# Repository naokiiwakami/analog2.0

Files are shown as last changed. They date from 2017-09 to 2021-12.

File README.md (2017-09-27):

# Analog2.0

Analog2.0 は、はじめての人でも作りやすいように設計されたモジュラーシステムシンセサイザーです。

このリポジトリには、Analog2.0 の製作を支援するための以下のようなリソースが置いてあります

- 回路図のイメージファイル
- 基板のレイアウトのファイル
- パネルなどのアートワークファイル
- ファームウェアとソースコード

また、製作ガイドをこのリポジトリの Wiki ページに掲載しています。

https://github.com/naokiiwakami/analog2.0/wiki

Analog2.0 は、以下の主要モジュールで構成されています。このリポジトリには、モジュールごとのディレクトリがあり、各ディレクトリの下にそのモジュール製作のためのリソースが置いてあります。

- `02_panel` パネル
- `03_power` 電源モジュール
- `04_noise_mixer` ノイズ・ジェネレータとミキサ
- `05_vca` VCA -- 電圧制御増幅器
- `06_vco` VCO -- 電圧制御発振器
- `07_eg` エンベロープ・ジェネレータ
- `08_lfo` LFO -- 低周波発振器
- `09_vcf` VCF -- 電圧制御フィルタ
- `10_miniboard` MIDI / CV 変換器

参考として、Analog2.0 のシステムに準じてはいないけれどもシンセサイザーのモジュールとして使えるものが `others` ディレクトリにおいてあります。

- リングモジュレータ
- グラフィックイコライザ
- レゾネータ
- フェーズシフタ
- ゲートディレイ
- アナログシーケンサ

各モジュールのドキュメントは現在メインテナンスしていません。最新のドキュメントは、書籍「達人と作るアナログシンセサイザー自作入門　改訂版2017」として出版されています

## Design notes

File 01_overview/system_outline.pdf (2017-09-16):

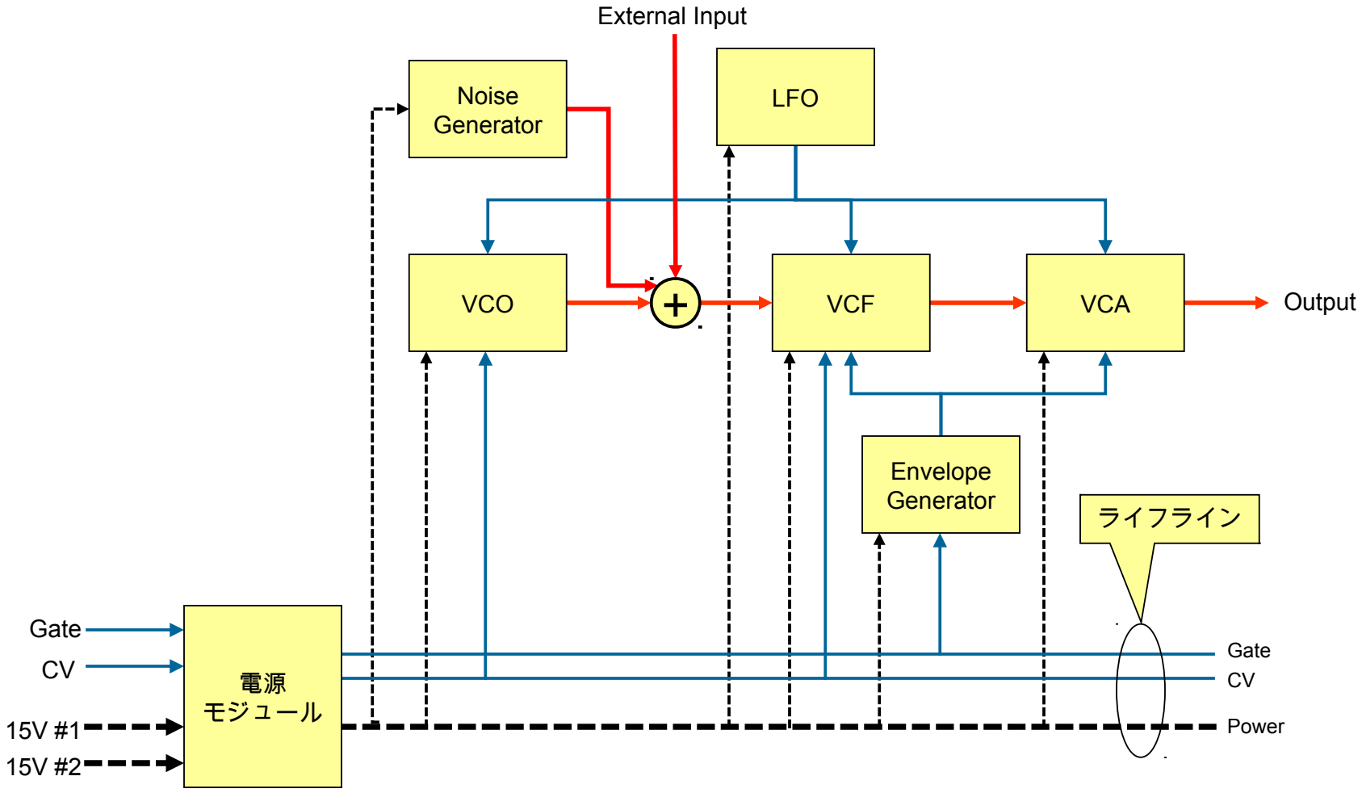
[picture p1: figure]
External Input; Output; Gate; ライフライン; Gate CV; Power; VCO; Noise Generator; VCF; VCA; LFO; Envelope Generator; 電源 モジュール

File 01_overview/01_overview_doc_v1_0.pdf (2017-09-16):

### Analog 2.0 ドキュメンテーション

### Vol. 1

## Analog2.0 の概要

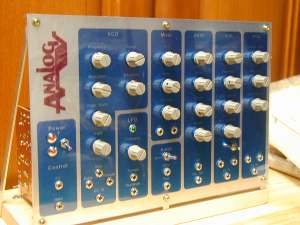
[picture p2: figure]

バージョン：1.0
作成日：2008 年 1 月 24 日

Analog2.0 ドキュメンテーション
Vol.1 Analog2.0 の概要
Copyright (C) Naoki Iwakami. All rights reserved. | 2

目次

1. このドキュメントについて | 3 ...... 3

Copyright (C) Naoki Iwakami. All rights reserved. | 3
1. このドキュメントについて

このドキュメントは、アナログシンセサイザーシステム Analog2.0 の概要を解説します。

このドキュメントは以下のように構成されています。

- Analog2.0 とは
- Analog2.0 の構成
- ドキュメントのリリース予定
2. Analog2.0 とは

Analog2.0 は、アナログシンセサイザーシステムの設計の名称です。以下のようなコンセ プトのもとに設計されており、製作を解説するドキュメントの形式で公開されます。

【対象】 | アナログシンセサイザーを作ってみたい人。ただ作るだけでなく、いずれ は自分のカラーを出して作りたい人。
【構成】 | 最小構成のモノフォニック。内部結線を行い、パッチングをしなくても音 は出せるがパッチも可能にする。機能モジュールごとに基板を分け、拡張 や改造を容易にする。

【必要な知識】 オームの法則がわかる。電流と電圧の違いがわかる。アナログオーディオ
| 信号とは音波を電圧に置き換えたものだということを理解している。

【必要な道具】 ハンダゴテ（と半田）、ラジオペンチ、ニッパー、ドライバー、ドリル、
| テスター、アンプとスピーカー、PC。
【進め方】 | まずパネルを製作する。定期的にシンセモジュールの製作方法を１個ずつ リリース。これを組み立ててパネルにはめてゆく。製作方法の説明に加え て毎回テーマを決めてアナログシンセサイザーの動作原理を解説する。
【部品】 | 全ての回路を現状入手可能な部品のみで構成する。
【提供物】 | 製作ガイドを提供。部品および基板の提供はこのプロジェクトの範囲に含 まない

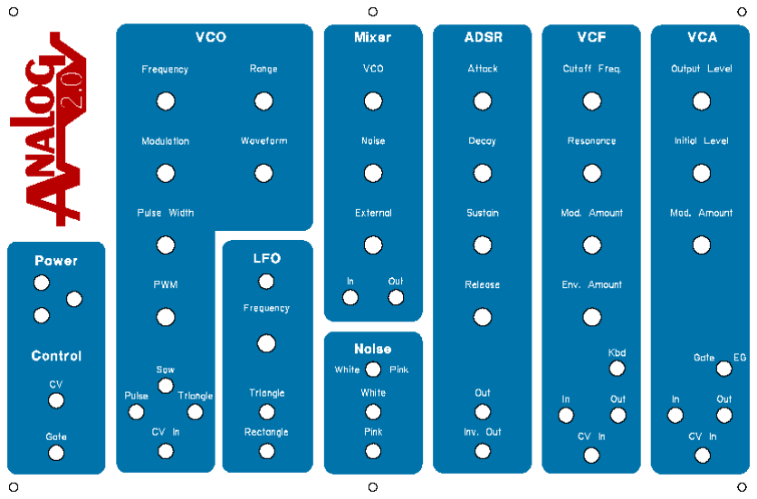
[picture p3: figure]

Copyright (C) Naoki Iwakami. All rights reserved. | 4
3. Analog2.0 の設計概要
3.1. システム構成
図 3-1 は、Analog2.0 のパネル設計例です。以下のモジュールで構成されています。
- 電源
- VCO
- LFO
- ミキサー
- ノイズ・ジェネレータ
- エンベロープ・ジェネレータ
- VCF
- VCA

全体をコントロールするための CV と Gate 信号は、外部入力します。

図 3-1 Analog2.0 Analog2.0のパネル

これらのモジュールは、図 3-2 のシステムブロックダイアグラムにあるように、あらかじめ 内部結線されます。これは、使用を簡単にするためですが、また自由度を高めるために簡 易なパッチシステムも持ちます。

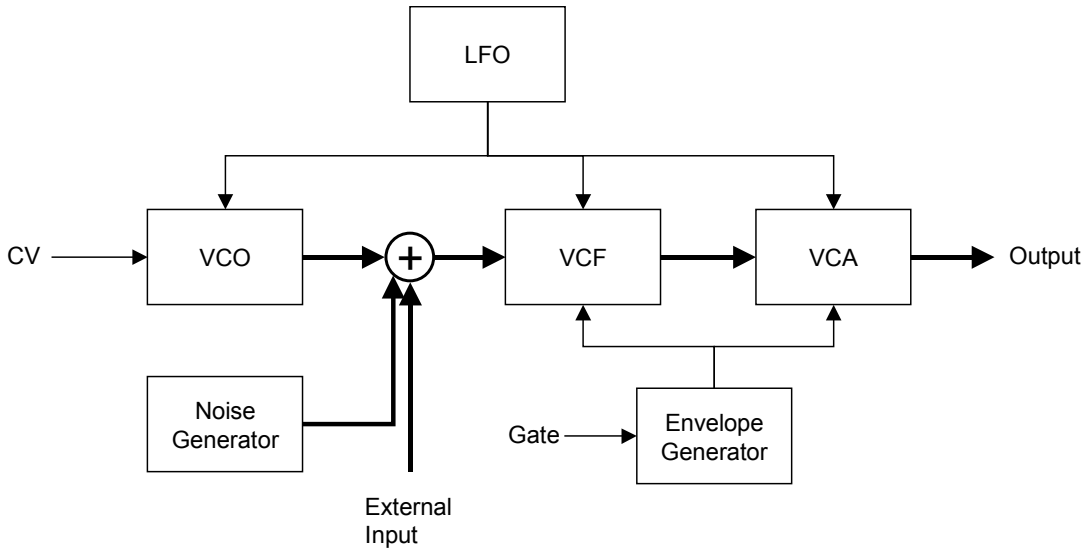
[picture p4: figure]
VCO; Noise Generator; VCF; VCA; LFO; Envelope Generator; External Input; Output; Gate
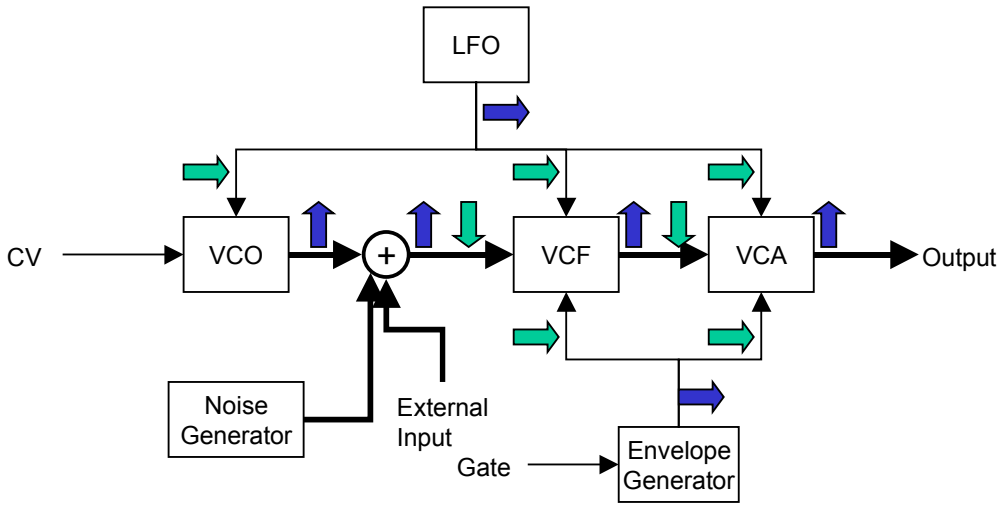
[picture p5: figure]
VCO; Noise Generator; VCF; VCA; LFO; Envelope Generator; External Input; Output; Gate

Copyright (C) Naoki Iwakami. All rights reserved. | 5

図 3-2 Analog2.0 Analog2.0 のシステムブロックダイアグラム のシステムブロックダイアグラム

図 3-3 はパッチシステムの概要です。矢印がパッチ箇所です。 緑色の矢印は、入力用パッチジャックの位置を示しています。入力用パッチジャックにパ ッチプラグをさすと、その部分の内部結線は切断され、挿入したパッチプラグからの信号 が使われます。青色の矢印は、出力用パッチジャックの位置を示します。

図 3-3 パッチシステム

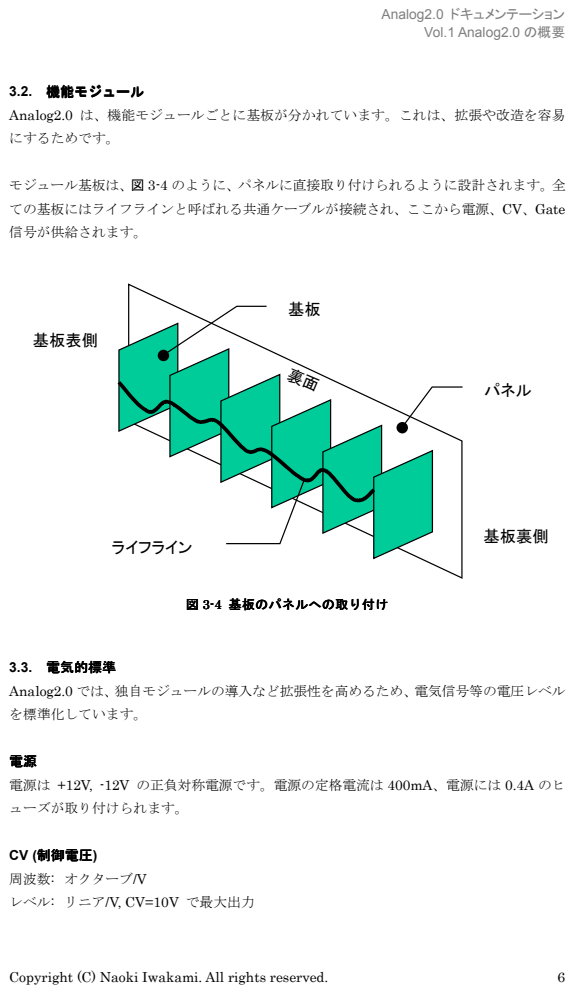
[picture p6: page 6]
Copyright (C) Naoki Iwakami. All rights reserved.; 図 3-4 基板のパネルへの取り付け; パネル; ライフライン; 基板表側; 基板裏側

3.2. 機能モジュール
Analog2.0 は、機能モジュールごとに基板が分かれています。これは、拡張や改造を容易
にするためです。

モジュール基板は、図 3-4 のように、パネルに直接取り付けられるように設計されます。全
ての基板にはライフラインと呼ばれる共通ケーブルが接続され、ここから電源、CV、Gate
信号が供給されます。

3.3. 電気的標準
Analog2.0 では、独自モジュールの導入など拡張性を高めるため、電気信号等の電圧レベル
を標準化しています。

電源は +12V, -12V の正負対称電源です。電源の定格電流は 400mA、電源には 0.4A のヒ
ューズが取り付けられます。

CV (制御電圧)
周波数: オクターブ/V
レベル: リニア/V, CV=10V で最大出力

Copyright (C) Naoki Iwakami. All rights reserved. | 7

Gate
off : | 0V
on : | 5V

信号レベル
音源 (VCO/Noise): | -5V to 5V (10V p-p)
LFO: | -2.5V to 2.5V (5V p-p)
EG: | 0-8V
4. ドキュメントの構成予定

Analog2.0 のドキュメントは、以下のように順次リリースされます。

Vol. | タイトル | 内容
1 | Analog2.0 の概要 | このドキュメント
2 パネルの製作
3 | 電源とライフラインの製作 | 解説：電圧と電流
4 | ノイズジェネレータとミキサーの製作 | 解説：トランジスタ・オペアンプの基礎
5 | VCA の製作 | 解説：ボルテージコントロール
6 | エンベロープ・ジェネレータの製作 | 解説：ディジタル回路の基礎
7 | VCO の製作 | 解説：発振回路
8 | LFO の製作 | 解説：モジュレーション
9 | VCF の製作 | 解説：フィルターの原理と制御方法

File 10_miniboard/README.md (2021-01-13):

# Mini Board 2

## Mini Board 2 とは

 MInIBoard 2 は、Analog2.0 の簡易的なコントローラです。

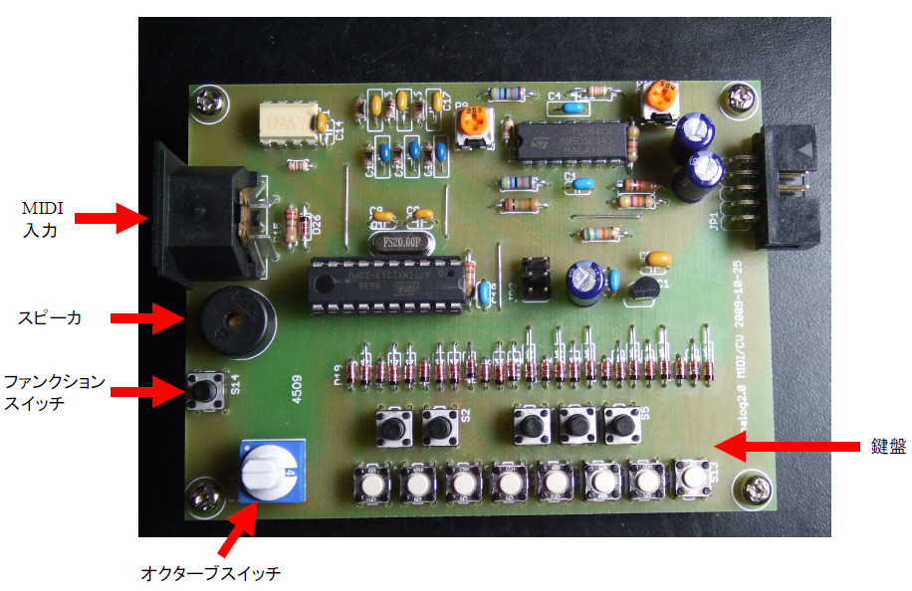
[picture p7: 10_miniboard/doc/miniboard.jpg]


以下のような機能を持っています。

- ライフラインケーブルに接続して、CV と Gate 信号を発生する。CV および Gate はライフラインのバスに出力する。
- CV と Gate は基板上の鍵盤または MIDI コネクタから入力した MIDI 信号により発生させます。
  - 基板上の鍵盤を使ってオクターブスイッチで指定したオクターブ上の CV を発生させます。例えば、オクターブスイッチで“4” を指定してAの鍵盤を押すと、A4 に相当する CV を発生します。
  - ファンクションスイッチを1秒間押し続けると、スピーカから 440 Hzの基準音が出力されます。基準音を止めるときにはファンクションスイッチをまた1秒間押し続けます。
- MIDI から CV と Gate 信号を発生させる時のふるまいは以下の通りです。
  - モノフォニック。同時に複数のノートONが入力された場合、高音が優先されます。
  - 複数のノートONが入力されたとき、二番目以降のONに対してリトリガーは行われません。
  - MIDI のピッチベンドメッセージを認識してCVを変化させます。

## 回路図

[doc/miniboard_schematic.pdf](doc/miniboard_schematic.pdf)
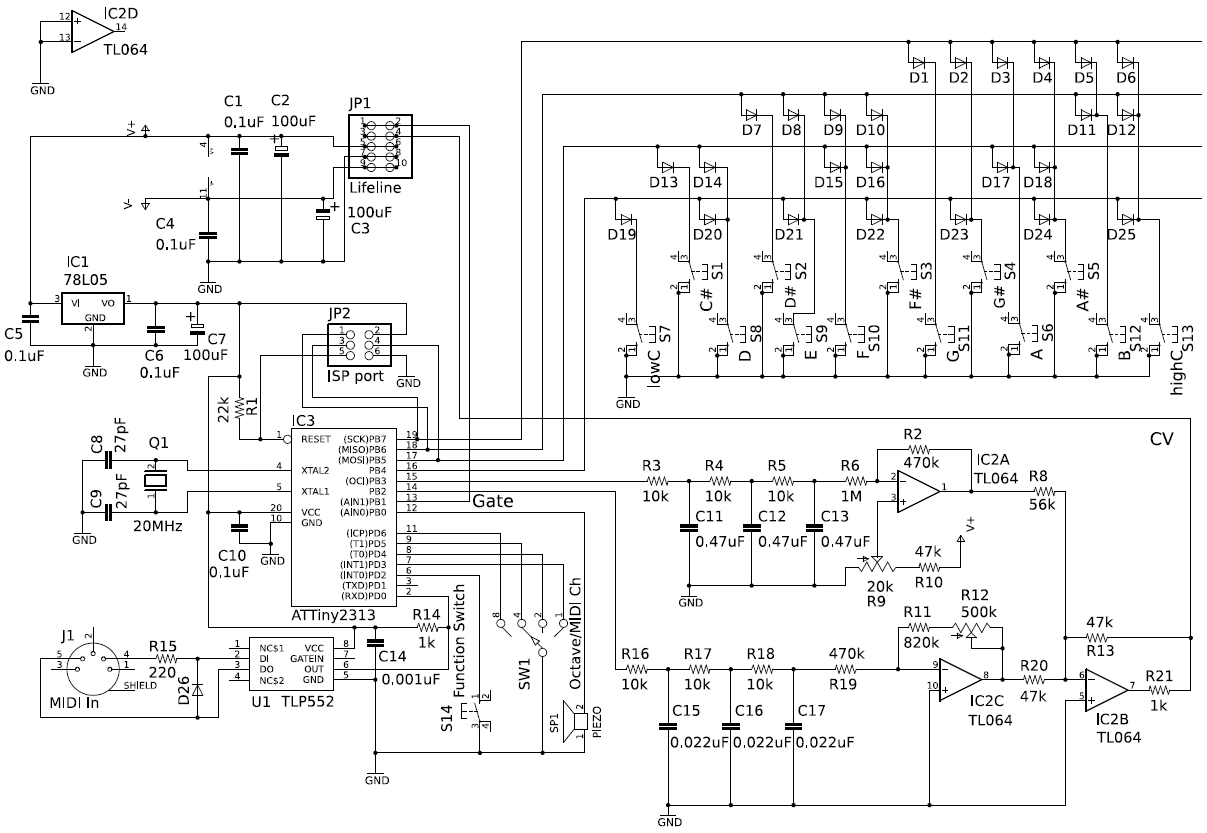
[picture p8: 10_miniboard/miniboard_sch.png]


## パーツリスト

[miniboard_parts_list.md](miniboard_parts_list.md)

## ファームウェア

MiniBoard 2 を動かすには、AVR マイクロプロセッサ ATTiny2313 にファームウェアを書き込む必要があります。

ファームウェアの書き込みの方法については、[ファームウェアの解説ページを参照してください](doc/Firmware.md)。

最新のビルド済みファームウェア： [firmware/releases/miniboard_20210113.zip](firmware/releases/miniboard_20210113.zip)

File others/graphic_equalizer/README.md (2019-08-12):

# グラッフィック・イコライザ

## 概要

グラフィックイコライザは、多数並んだ周波数バンドごとに共振フィルタを持っており、周波数バンドごとに周波数特性を強調したり弱めたりできます。このグラフィックイコライザには、1オクターブごとの7バンドがあります。

## このディレクトリに含まれるリソース

- graphic_equalizer.CE3: 回路図ファイル (BSch3v)
- graphic_equalizer_sch.pdf, graphic_equalizer_sch.png: 回路図イメージファイル

## 回路図

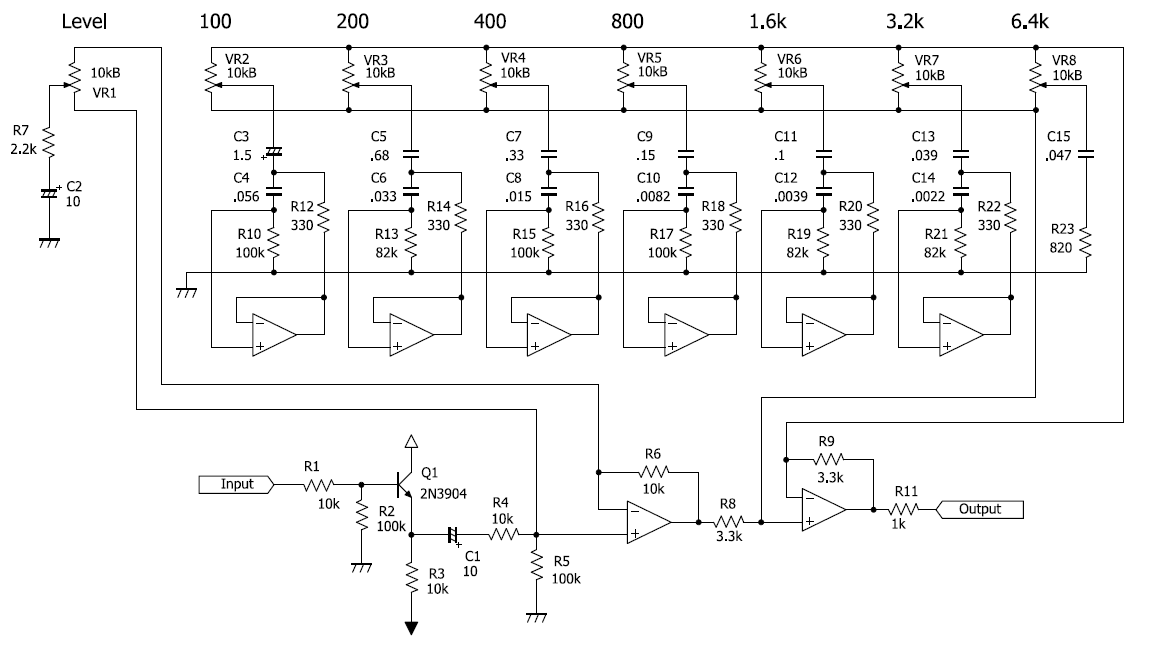
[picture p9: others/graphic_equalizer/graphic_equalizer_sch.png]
graphic equalizer


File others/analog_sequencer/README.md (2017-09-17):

# アナログシーケンサ

## 概要

アナログシーケンサはCVを発生するボリュームが並んでおり、これを逐次切り替えることでCVのパタンを発生します。ここでの作例は、8ステップのシーケンサが2個並んだ構造になっています。これを直列に走らせると16ステップ1系統のシーケンサになります。並列に走らせると8ステップ2系統のシーケンサになります。parrarel/serialスイッチで切り換えられます。また、One ShotスイッチをONにすると、一回だけシーケンスを再生して停止します。

CVは、Parrarelモードでは、CV Out1、CV Out2から別々に2系統が出力されます。Serialモードでは、CV Out1、CV Out2どちらからも同等の16ステップ分の一系統が出力されます。

## このディレクトリに含まれるリソース

- analog_sequencer_sch.pdf, analog_sequencer_sch.png: 回路図イメージファイル
- Eagle ファイル、Eagle ver. 5.12 で作成しています。プリント基板レイアウトファイルは未作成です。
  - eagle/eagle.epf - プロジェクトファイル
  - eagle/analog_sequencer.sch - 回路図ファイル

## 回路図

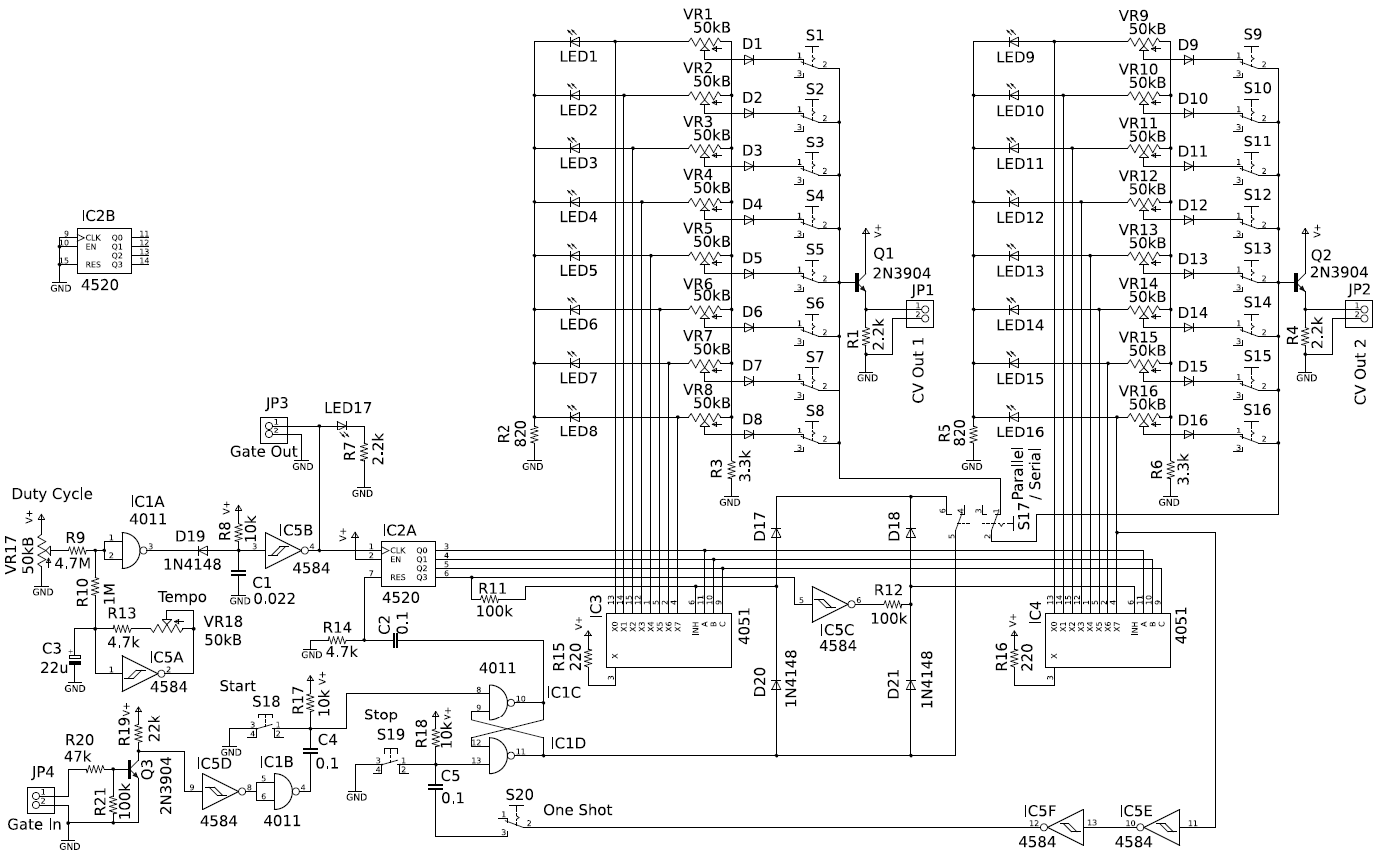
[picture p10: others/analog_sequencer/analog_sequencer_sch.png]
analog sequencer


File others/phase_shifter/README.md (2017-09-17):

# フェーズシフタ

## 概要

フェーズシフタはシンセサイザーのモジュールというより、どちらかというとエフェクタとしてよく知られています。もともとは回転スピーカの効果に似た音を得るために考案されたようですが、実のところあまり似ていません。それでも、音がうねるような独特の面白い効果が得られることから重宝されているエフェクタです。回路図は次ページの通りです。

## このディレクトリに含まれるリソース

- phase_shifter_sch.pdf, phase_shifter_sch.png: 回路図イメージファイル
- Eagle ファイル、Eagle ver. 5.12 で作成しています
  - eagle/eagle.epf - プロジェクトファイル
  - eagle/phaser.sch - 回路図ファイル
  - eagle/phaser.brd - 基板レイアウトファイル

## 回路図

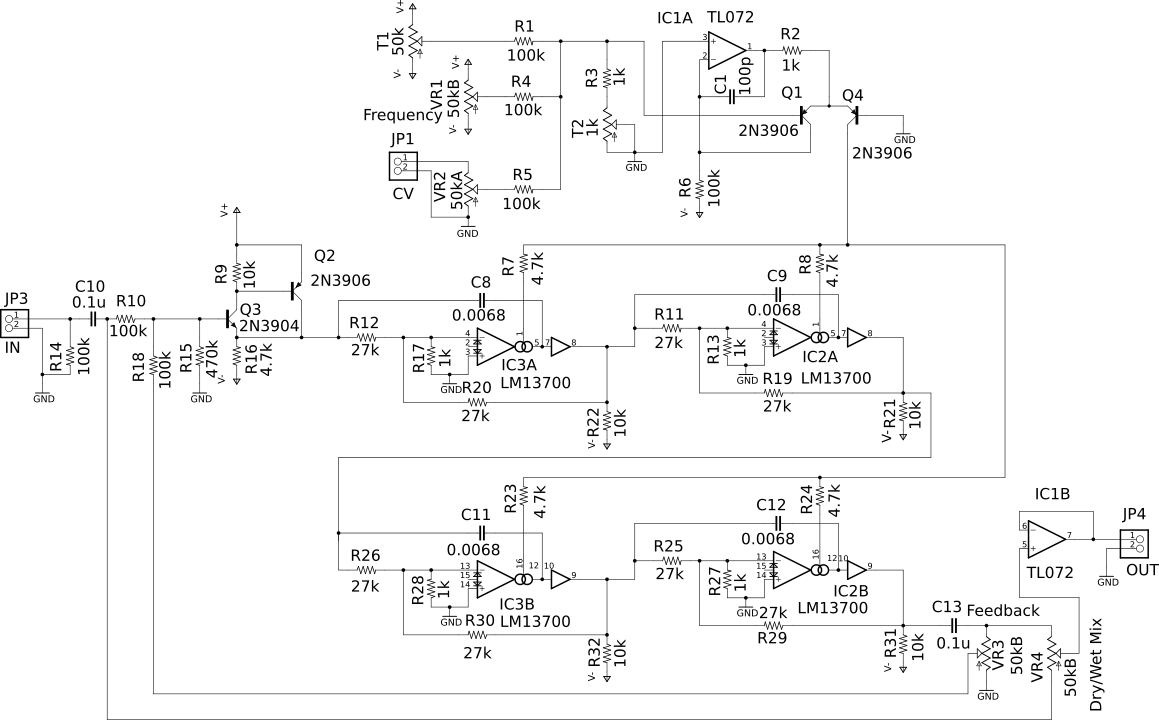
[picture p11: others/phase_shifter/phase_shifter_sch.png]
phase shifter


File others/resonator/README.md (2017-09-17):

# レゾネータ

## 概要

レゾネータは「共振器」という意味です。入力信号に周波数特性のピークをつけるフィルタです。グラフィックイコライザと比べて一般的にバンド数が少なく、その代わりフィルタの中心周波数と共振の鋭さが細かく調整できます。こういったフィルタは楽器固有の共鳴などの現象と同じような効果を得るのに向いているため、音声に似た音を作ったり、楽器音をより本物らしくしたりできます。このレゾネータは3個のフィルタを持っています。

## このディレクトリに含まれるリソース

- resonator_sch.pdf, resonator_sch.png: 回路図イメージファイル
- Eagle ファイル、Eagle ver. 5.12 で作成しています
  - eagle/eagle.epf - プロジェクトファイル
  - eagle/resonator2.sch - 回路図ファイル
  - eagle/resonator2.brd - 基板レイアウトファイル

## 回路図

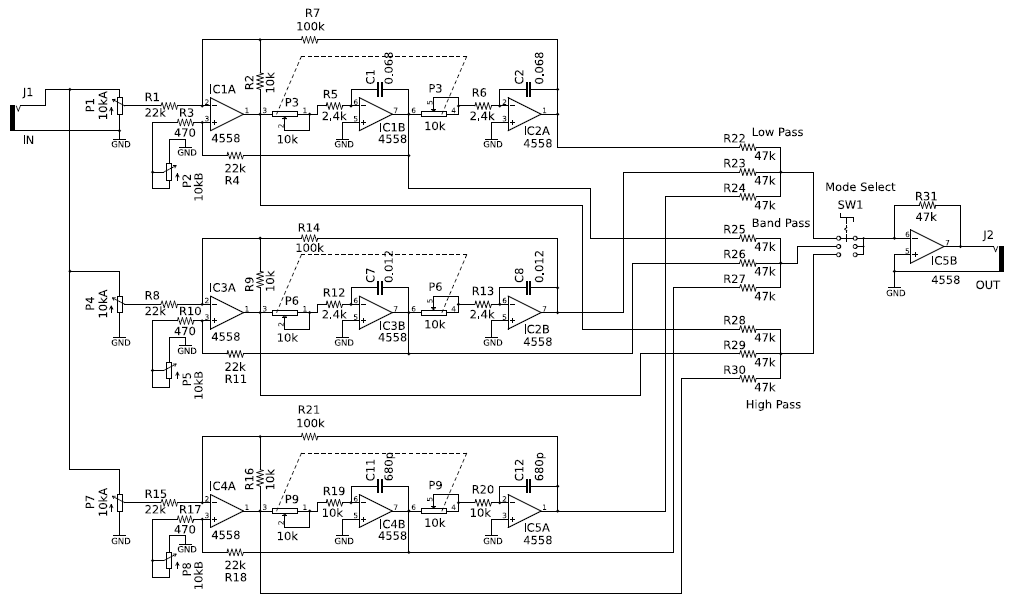
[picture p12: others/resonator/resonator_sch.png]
resonator


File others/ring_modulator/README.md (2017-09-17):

# リング・モジュレータ

## 概要

リングモジュレータは、ピッチ感はあるのに音階がはっきりしない音を作るのに向いているモジュールです。2系統の入力と一系統の出力を持ちます。2つの入力を掛け合わせて出力を得ます。

## このディレクトリに含まれるリソース

- ring_modulator.ce3: 回路図ファイル (BSch3v)
- gate_delay_sch.pdf, gate_delay_sch.png: 回路図イメージファイル

## 回路図

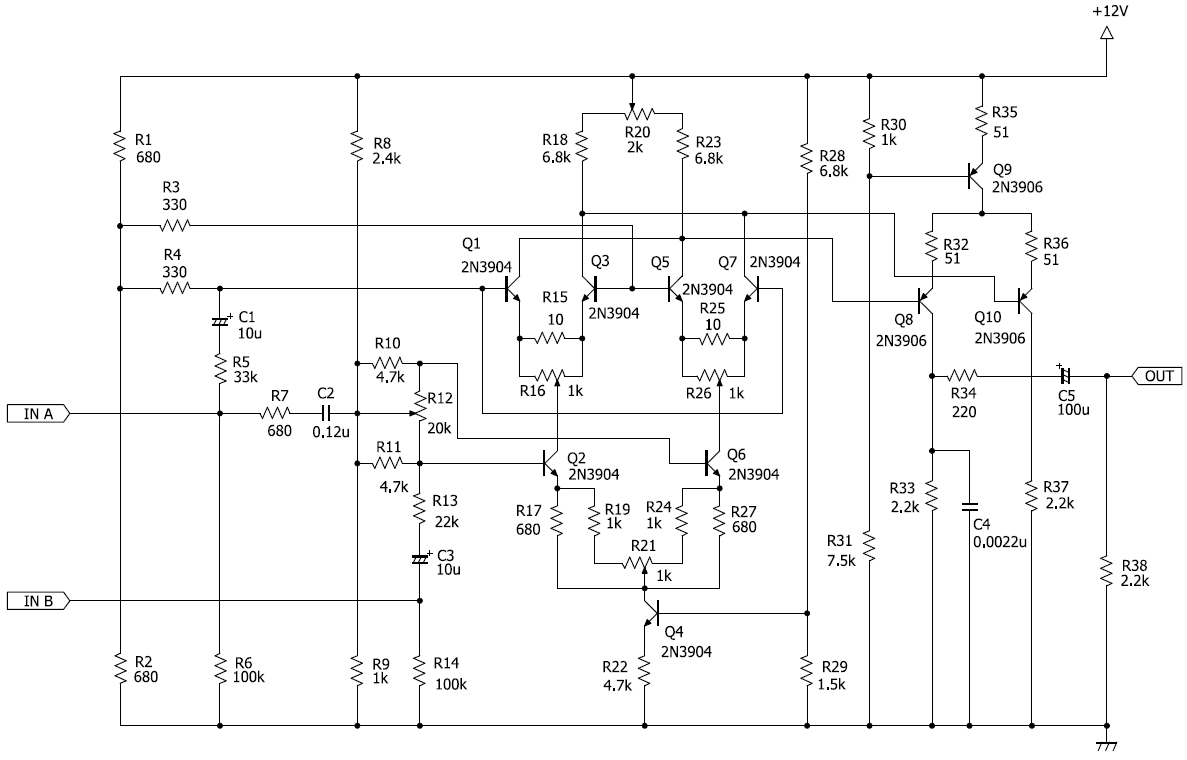
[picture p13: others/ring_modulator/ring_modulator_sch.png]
ring modulator


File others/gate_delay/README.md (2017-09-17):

# ゲートディレイ

## 概要

ゲートディレイは入力されたゲート信号を遅延させて出力させます。単一出力と加算出力を持ち、単一出力では遅延したゲート信号のみを出力し、加算出力ではもとのゲート信号と加えます。

## このディレクトリに含まれるリソース

- gate_delay.ce3: 回路図ファイル (BSch3v)
- gate_delay_sch.pdf, gate_delay_sch.png: 回路図イメージファイル

## 回路図

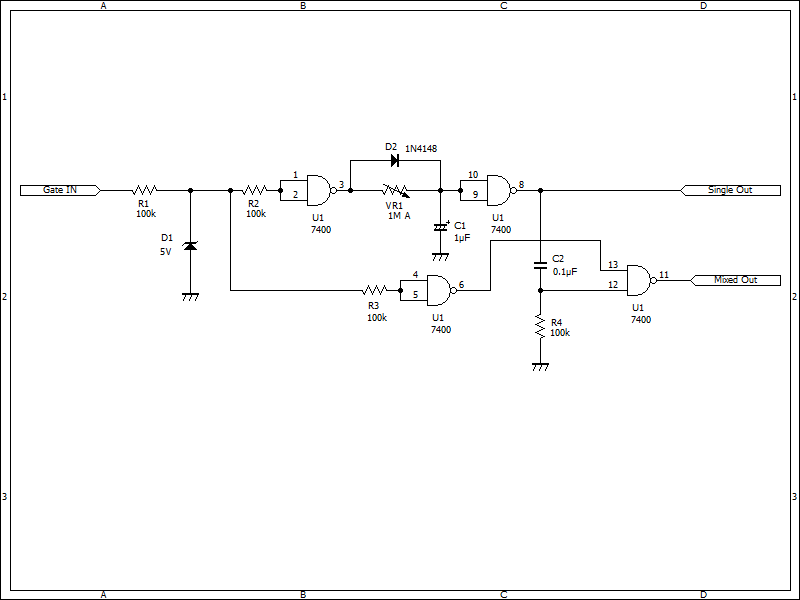
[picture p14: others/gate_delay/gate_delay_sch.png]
gate delay


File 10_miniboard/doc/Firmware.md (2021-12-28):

# ファームウェア

MiniBoard 2 を動かすには、AVR マイクロプロセッサ ATTiny2313 にファームウェアを書き込む必要があります。
ファームウェアは、ビルド済みのものをこのリポジトリからダウンロードするか、ソースコードからビルドすることによって入手できます。

## ファームウェアのダウンロード
リポジトリ内のディレクトリ [10_miniboard/firmware/releases](../firmware/releases/)
からファイル名についている日付の一番新しい zip ファイルをダウンロードしてください。

zip ファイル内には、以下のファイルが含まれています。

- a20_midi.elf : ファームウェアイメージ 
- a20_midi.hex : プログラム領域の hex データファイル
- a20_midi.c : ソースコード
- Readme.txt : Fuse バイト情報など
- LICENSE : ライセンスファイル

## ビルド方法

ビルドには、ソフトウェア Atmel Studio 7 が必要です。

http://www.atmel.com/microsite/atmel-studio/

ディレクトリ [10_miniboard\firmware\miniboard2_firmware](../firmware/miniboard2_firmware) の下の Atmel Studio ソリューションファイル [firmware.atsln](../firmware/firmware.atsln) を開いて、
プロジェクト `miniboard2_firmware` をビルドしてください。ファームウェアはプロジェクトディレクトリの下の `Release` ディレクトリにビルドされます。
ファイル名は `a20_midi.elf` と `a20_midi.hex`です。

## ファームウェアのプロセッサへの書き込み

### 書き込みに必要なもの

ファームウェアの書き込みには、以下のものが必要です。

- **ファームウェアイメージ** <br />
  上述のとおり

- **AVRプログラマ (ハードウェア)** <br />
  「AVRライタ」とも呼ばれます。AVRプロセッサに書き込みを行うためのデバイスです。
  Atmel / Microchip の安価な純正品だった [AVRISP mkII](http://www.atmel.com/tools/avrispmkii.aspx) は残念ながら販売終了してしまいました。ほかに入手可能な純正品には、以下のようなものがあります。

  - [AVR Dragon](http://www.atmel.com/tools/avrdragon.aspx)
  - [ATAtmel-ICE](http://www.atmel.com/tools/atatmel-ice.aspx)

  純正品でない安価なプログラマも入手可能です。

  以下は、書き込みができることを確認したプログラマです。

  - Atmel / Microchip <br />
    - AVRISP mkII http://www.atmel.com/tools/avrispmkii.aspx
  - サードパーティー <br />
    - Aitendo USB-ASP2 http://www.aitendo.com/product/10259<br />
      元となったプログラマ http://www.fischl.de/usbasp/

- **AVRプログラマ (ソフトウェア)** <br />
  実際に書き込みを行うソフトウェアです。Atmel Studio に付属しているので、Atmel Studio が認識できるプログラマなら別にソフトウェアを用意する必要はありません。そうでない場合、[AVRDUDE](http://www.nongnu.org/avrdude/) がよく使われるソフトウェアです。このページの書き込み例でも AVRDUDE を使います。

- **AVRプログラマとMiniboard II プロセッサをつなぐケーブル**

### プログラマ用ドライバのインストール
ほとんどの AVR プログラマが USB で接続するもので、何らかのドライバが必要です。以下は必要なドライバの概略です。

| プログラマ | Windows | Mac OS | Linux |
| --- | --- | --- | ----- |
| AVRISP mkII | Atmel Studio インストール時にUSBドライバもインストールする | TBD | TBD |
| AVR Dragon  | Atmel Studio インストール時にUSBドライバもインストールする | TBD | TBD |
| USB-ASP2 | [USBasp ドライバのインストール](#usbasp_driver) 参照 | 新たなドライバのインストールは不要 (10.11 El Capitan) | TBD |

### AVRDUDE のインストール

#### Windows

この例では、AVRDUDE を C:\avrdude ディレクトリにインストールします。

1. [AVRDUDE](http://www.nongnu.org/avrdude/) の [ダウンロードエリア](http://download.savannah.gnu.org/releases/avrdude/) に行き、最新版の Windows アーカイブをダウンロードします。(例: avrdude-6.3-mingw32.zip)
2. ディレクトリ C:\avrdude を作成します。
3. AVRDUDE アーカイブに含まれているファイル avrdude.conf と avrdude.exe をディレクトリ C:\avrdude に解凍します。
4. コントロールパネルを起動し、"edit environment variables" を検索します。見つかったリンクのうち、"Edit the system environment variable" をクリックすると、システムプロパティのダイアログが現れます。「環境変数」ボタンを押して、環境変数エディタを起動します。
5. System variables の Path に C:\avrdude を追加します。
6. コマンドプロンプトを立ち上げて、"avrdude -v" とタイプしてください。正しくインストールされていれば、AVRDUDE のバージョンが表示されます。

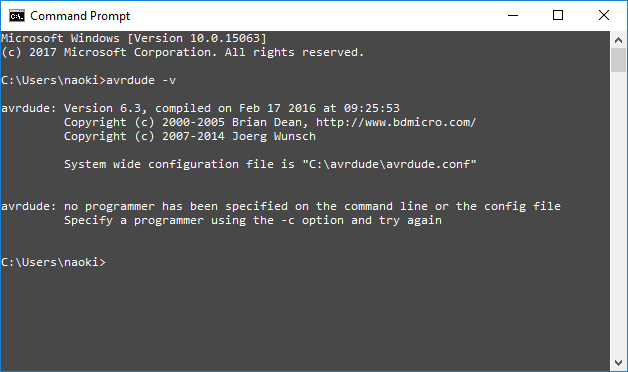
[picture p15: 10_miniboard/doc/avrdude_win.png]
avrdude


#### MacOS

[Homebrew](https://brew.sh/) というソフトウェアを使っていれば以下のように簡単にインストールできます。

```
$ brew install avrdude
```

参考： http://macappstore.org/avrdude/

#### Linux

TBD

### AVRプログラマを MiniBoard に接続

Miniboard 2 の基板には、6本ピンのプログラミング用端子がついています。これは Atmel AVRISP のピン配置に準拠しているので、AVRISP II からプログラミングする場合は、このプログラマについているケーブルの6ピンソケットをそのままさしてください。このピン配置に準拠していないプログラマを使う場合には、そのプログラマのピンと Miniboard 2 のプログラミング端子のピン名が一致するように接続してください。

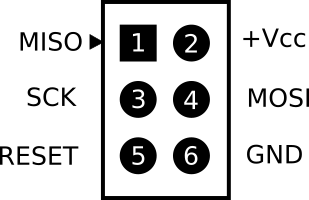
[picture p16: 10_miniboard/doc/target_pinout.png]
target_pinout


Miniboard 上のプログラミング端子を使わず、プロセッサ ATTiny2313 に直接書き込む場合には、以下のようにピンをつないでください。

| プログラマ | プロセッサのピン番号 |
| ----- | --- |
| +Vcc  | 20 |
| SCK | 19 |
| MISO  | 18 |
| MOSI  | 17 |
| GND | 10 |
| RESET | 1 |

### 書き込み

ここでは、Aitendo USB-ASP2 を MacOS 上で AVRDUDE を使って書き込む例を書きます。この場合には、Windows 以外では特別にドライバソフトウェアなどをインストール必要がないので、比較的簡単に書き込みができます。

USB-ASP2 の出力は 6 ピンではなく 10 ピンです。本体側（オス）コネクタのピン配置は以下の通りです。

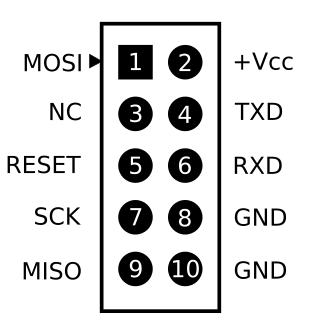
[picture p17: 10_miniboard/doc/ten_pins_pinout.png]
ten_pins_pinout


まずは、ファームウェアイメージのあるディレクトリに移動して、イメージファイルがあることを確認します。

```
$ ls a20_midi.hex
a20_midi.hex
```

次に、AVRDUDE を使ってファームウェアを書き込みます。hex ファイルには、プログラム領域のデータしか入っていないので fuse バイトも明示して書き込みます。

```
$ avrdude -c usbasp -p t2313 -U lfuse:w:0xff:m -U hfuse:w:0xdf:m -U efuse:w:0xff:m -U flash:w:a20_midi.hex
```

a20_midi.elf ファイルには fuse バイト情報も含まれているので、fuse にどんな値を入れるのか気にせず以下のように書き込むこともできます。ただし AVRDUDE はバージョン6以上のものを使う必要があります。

```
$ avrdude -c usbasp -p t2313 -U lfuse:w:a20_midi.elf -U hfuse:w:a20_midi.elf -U efuse:w:a20_midi.elf -U flash:w:a20_midi.elf
```

この操作で書き込みの確認も行われるので、実行が成功すればこれで書き込みは完了です。

参考までに、AVRDUDE の簡単なヘルプは -h オプション (`avrdude -h`) で見られますがあまり詳しくありません。詳しいマニュアルは

https://www.nongnu.org/avrdude/user-manual/avrdude.html

で読むことができます。

コマンドラインオプションはこちらのページに詳しく書かれています。

https://www.nongnu.org/avrdude/user-manual/avrdude_3.html#Option-Descriptions

### 動作確認
Miniboard のファンクションスイッチを一秒程度押し続けてください。書き込みが成功していれば 440Hz の基準音がスピーカから鳴ります。さらに一秒ほど押し続けると音は止まります。

## 付録

### USBasp ドライバのインストール (Windows)

参考：<br />
http://www.fischl.de/usbasp/<br />
http://ht-deko.com/arduino/usbasp.html

USBasp 互換のデバイスを Windows で使うためには、ドライバをインストールする必要があります。インストールには [Zadig](http://zadig.akeo.ie/) というツールを使います。

Zadig exe ファイルをダウンロードして、USBasp デバイスが USB にささっていない状態で実行してください。

以下のようなユーザ・アクセス・コントロールの承認ウィンドウが現れるので、yes ボタンを押して承認します。

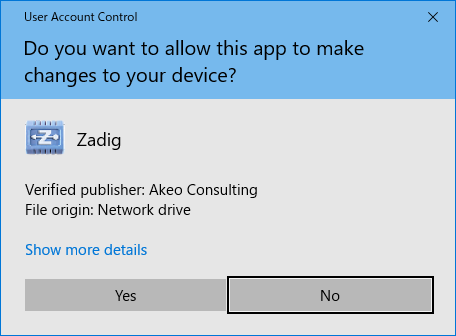
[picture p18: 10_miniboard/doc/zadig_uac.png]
uac


承認すると、Zadig アプリケーションが起動します。

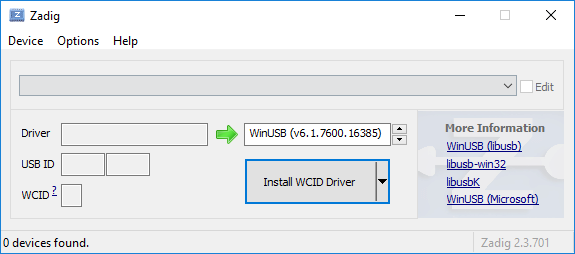
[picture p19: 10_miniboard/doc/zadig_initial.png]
initial


ここで、USBasp デバイスを PC に接続してください。以下のように、デバイスが認識されます。デバイスのドライバはまだインストールしていないので NONE になっています。インストールするドライバとして libusbK を選んで、"Install Driver" ボタンを押してください。

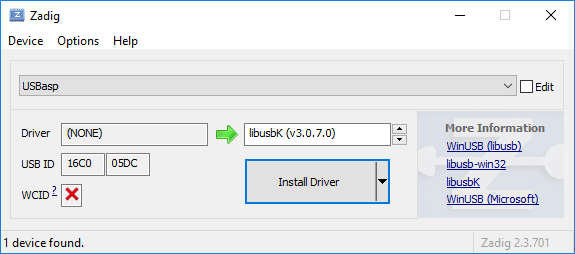
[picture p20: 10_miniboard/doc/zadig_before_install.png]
before_install


インストールに成功すると、以下のような画面になります。

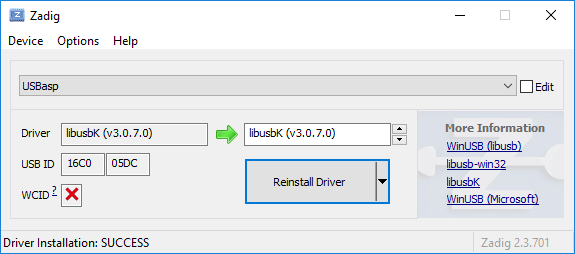
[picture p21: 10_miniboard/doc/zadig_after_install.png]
after_install


インストールが行われたかどうかの確認をするためには、コントロールパネル -> ハードウェアの設定 -> デバイスマネージャを呼び出してください。libusbK USB Devices の項目に USBasp が含まれていれば、正しくインストールされています。

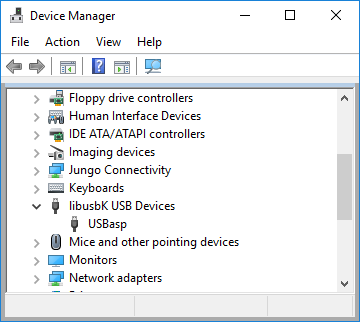
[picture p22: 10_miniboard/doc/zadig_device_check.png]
device_check


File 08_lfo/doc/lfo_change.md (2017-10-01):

# LFO回路の初版からの変更点

LFO回路は初版の時点の版から変更されています。変更点は以下の通りです。回路定数の変更ですから、基板の設計は初版のものと同じままです。

### 変更点

矩形波出力を減衰させる抵抗 R18 と R19 の値を変更しました。

新回路

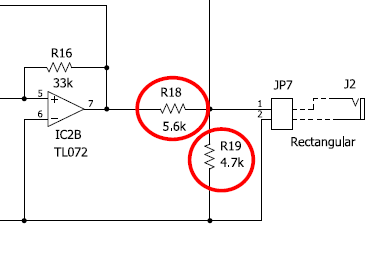
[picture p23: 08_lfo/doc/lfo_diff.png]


旧回路

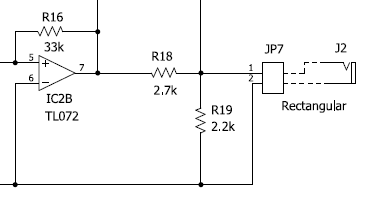
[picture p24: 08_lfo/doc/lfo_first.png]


### 理由

LFO回路の消費電流を小さくするためです。矩形波出力の消費電流が大きいと、電源電圧に影響を与えてしまい、それによりおなじライフラインにつないだ VCO のピッチが不安定になります。変更後 LFO が電源経由で VCO に影響を与える度合いが小さくなりました。

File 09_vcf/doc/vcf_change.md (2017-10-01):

# VCF 回路の初版からの変更点

VCF 回路は初版の時点の版から変更されています。変更点は以下の通りです。部品が追加されたため、改訂版向けの基板は初版向けのものから変更されています。

### 変更点

出力段にエミッタフォロワを入れました。

新回路



旧回路



### 理由

初版の回路では、JP1 経由の出力に低インピーダンスの負荷をつなげると、これが Q5, Q6, Q9, Q10 で構成した差動増幅器の出力に影響を与え、レゾナンスがうまく働かない問題がありました。この問題を避けるため、改訂版では出力段にエミッタフォロワを入れ、出力インピーダンスが差動増幅器に干渉しないようにしました。

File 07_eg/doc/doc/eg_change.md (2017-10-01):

# エンベロープ・ジェネレータ回路の初版からの変更点

エンベロープ・ジェネレータ回路は初版の時点の版から変更されています。変更点は以下の通りです。部品が追加されたため、改訂版向けの基板は初版向けのものから変更されています。

### 変更点

エンベロープジェネレータ出力段のエミッタフォロワを保護する抵抗 R21 を加えました。

新回路



旧回路



### 理由

初版の回路では、Q5 のエミッタフォロワ回路がそのまま JP3 経由で出力されています。JP3 にインピーダンスの非常に小さな負荷をつないでエンベロープ・ジェネレータを作動させると、Q5 が破損してしまう問題がありました。これを防ぐため、改訂版では Q5 を保護する抵抗 R21 が追加されています。

出力の低インピーダンス状態は、JP3 出力を誤って GND にショートさせてしまうと簡単に発生します。

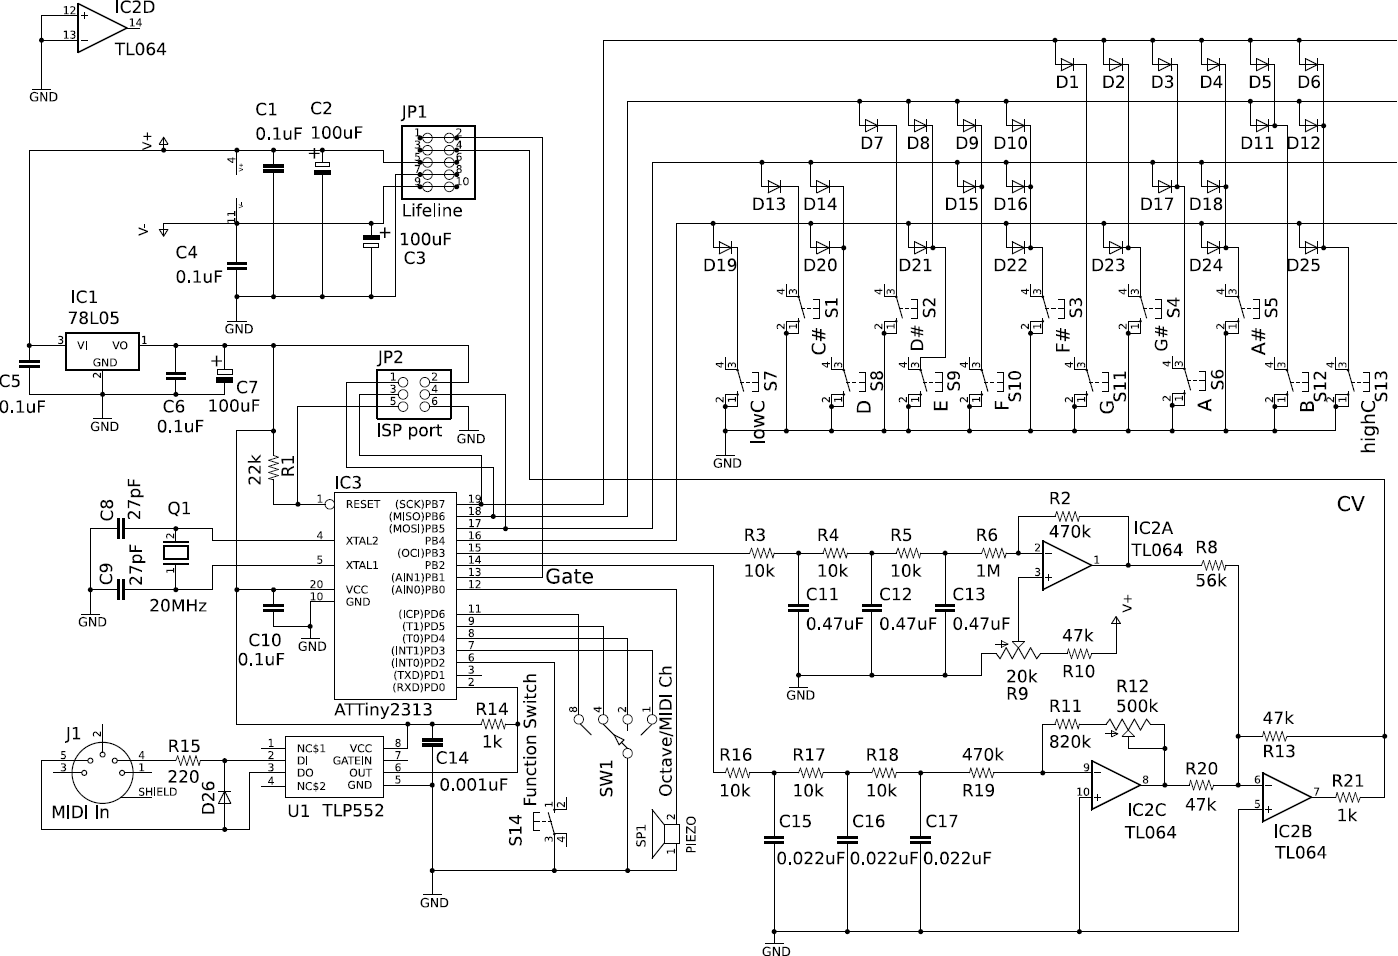
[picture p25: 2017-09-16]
10_miniboard/doc/miniboard_schematic.png

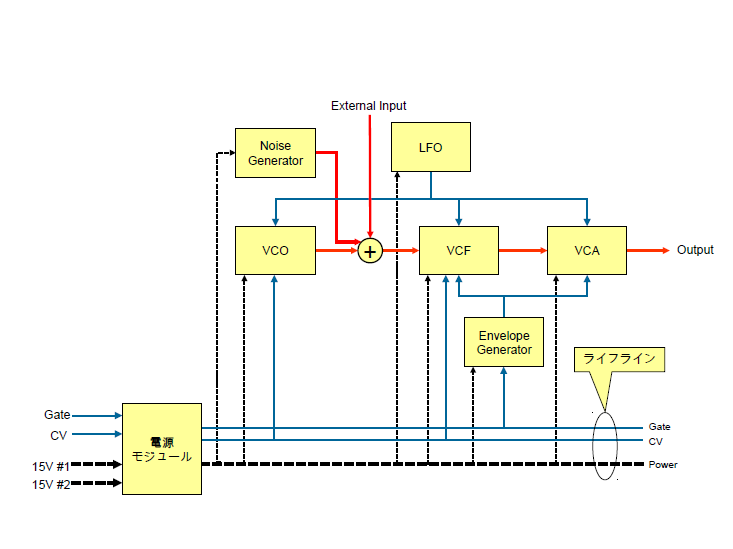
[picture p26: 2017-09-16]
01_overview/system_outline.png

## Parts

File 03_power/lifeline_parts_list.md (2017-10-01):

# ライフラインケーブルのパーツリスト

| 部品番号 | デバイス名 | 値/型番 | 備考 |
| --- | --- | --- | --- |
| CN1-7 | ヘッダソケットMILスタンダード | 10P (2x5) 2.5mmピッチ | 7個必要 |
|  | フラットケーブル10芯 | 55cm |

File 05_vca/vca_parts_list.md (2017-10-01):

# VCA モジュールのパーツリスト

### VCAの製作に必要な部品（基板上）

| 部品番号  | デバイス名 | 値 | 備考 |
| ----- | --- | --- | --- |
| C1 | 電解コンデンサ | 100μF 25V | |
| C2 | 電解コンデンサ | 100μF 25V | |
| C3 | 電解コンデンサ | 100μF 25V | |
| C4 | セラミックコンデンサ | 100pF | |
| C5 | 積層セラミックコンデンサ | 0.1μF | |
| C6 | 積層セラミックコンデンサ | 0.1μF | |
| D1 | ダイオード | 1N4148 | |
| D2 | ダイオード | 1N4148 | |
| D3 | ダイオード | 1N4148 | |
| IC1 | オペアンプ | TL072 | |
| JP1 | ピンヘッダ | 2.5mmピッチ 3P | EG/Gate Select |
| JP2 | ピンヘッダ | 2.5mmピッチ 2P | EG In |
| JP3 | ピンヘッダ | 2.5mmピッチ 2P | Audio In |
| JP4 | ピンヘッダ | 2.5mmピッチ 2P | Audio Out |
| JP5 | ボックスピンヘッダ | 2.5mmピッチ 2x5P L字型 | ライフライン |
| JP6 | ピンヘッダ | 2.5mmピッチ 2P | Ext CV |
| Q1 | トランジスタ | 2N3904 | |
| Q2 | トランジスタ | 2N3904 | |
| Q3 | トランジスタ | 2N3904 | |
| R1 | 抵抗器 | 39kΩ | |
| R2 | 抵抗器 | 22kΩ | |
| R3 | 抵抗器 | 22kΩ | |
| R4 | 抵抗器 | 47kΩ | |
| R5 | 抵抗器 | 10kΩ | |
| R6 | 抵抗器 | 1kΩ | |
| R7 | 抵抗器 | 10kΩ | |
| R8 | 抵抗器 | 150kΩ | |
| R9 | 抵抗器 | 100kΩ | |
| R10 | 抵抗器 | 1MΩ | |
| R11 | 抵抗器 | 100kΩ | |
| R12 | 抵抗器 | 150kΩ | |
| R13 | 抵抗器 | 47kΩ | |
| R14 | 抵抗器 | 1kΩ | |
| R15 | 抵抗器 | 1kΩ | |
| R16 | 抵抗器 | 22kΩ | |
| R17 | 抵抗器 | 6.8kΩ | |
| R18 | 抵抗器 | 68kΩ | |
| R19 | 抵抗器 | 47kΩ | |
| R20 | 抵抗器 | 22kΩ | |
| TRIM1 | 半固定抵抗 | 1kΩ | |
| TRIM2 | 半固定抵抗 | 50kΩ | |
| TRIM3 | 半固定抵抗 | 50kΩ | |
| VR1 | 可変抵抗 | 50kΩA | 基板垂直じか付け 2.5mm ピッチ |
| VR2 | 可変抵抗 | 50kΩA | 基板垂直じか付け 2.5mm ピッチ |
| VR3 | 可変抵抗 | 50kΩA | 基板垂直じか付け 2.5mm ピッチ |

### VCAの製作に必要な部品（基板外）

| 部品番号 | デバイス名 | 値/型番 | 備考 |
| ---- | --- | --- | --- |
| J1 | 3.5mm ジャック | スイッチつき | Audio In |
| J2 | 3.5mm ジャック | | Audio Out |
| J3 | 3.5mm ジャック | スイッチつき | Ext CV |
| SW1  | 3P トグルスイッチ | | EG/Gate Select |

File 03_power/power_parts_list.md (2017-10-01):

# 電源モジュール パーツリスト

### 電源モジュールの製作に必要な部品 (基板内)

| 部品番号 | デバイス名 | 値/型番 | 備考 |
| ---- | --- | --- | --- |
| C1 | 電解コンデンサ | 220μF 35V | |
| C2 | ポリエステルコンデンサ  | 0.33μF | 積層セラミックでも可 |
| C3 | 積層セラミックコンデンサ | 0.1μF | |
| C4 | ポリエステルコンデンサ  | 0.33μF | 積層セラミックでも可 |
| C5 | 積層セラミックコンデンサ | 0.1μF | |
| C6 | 電解コンデンサ | 1μF 25V | |
| C7 | 電解コンデンサ | 220μF 35V | |
| D1 | ショットキーダイオード  | 1N5819 | 同等品でも可。40V 1A  |
| D2 | ショットキーダイオード  | 1N5819 | 同等品でも可。40V 1A  |
| D3 | 整流用ダイオード | 1N4002 | 同等品でも可。100V 1A |
| D4 | 整流用ダイオード | 1N4002 | 同等品でも可。100V 1A |
| D5 | 整流用ダイオード | 1N4002 | 同等品でも可。100V 1A |
| D6 | 整流用ダイオード | 1N4002 | 同等品でも可。100V 1A |
| D7 | ショットキーダイオード  | 1N5819 | 同等品でも可。40V 1A  |
| D8 | ショットキーダイオード  | 1N5819 | 同等品でも可。40V 1A  |
| F1 | ポリスイッチ | 0.4A | |
| F2 | ポリスイッチ | 0.4A | |
| IC1  | 正電源三端子レギュレータ | TA7812 | 同等品でも可。12V |
| IC2  | 負電源三端子レギュレータ | TA7912 | 同等品でも可。-12V |
| J1 | DCジャック | 2.1mm | |
| J2 | DCジャック | 2.1mm | |
| JP1  | ピンヘッダ | 2.5mmピッチ 2ピン | |
| JP2  | ピンヘッダ | 2.5mmピッチ 2ピン | |
| JP3  | ピンヘッダ | 2.5mmピッチ 2ピン | |
| JP4  | ボックスピンヘッダ | 2.5mmピッチ 2x5ピン | |
| JP5  | ボックスピンヘッダ | 2.5mmピッチ 2x5ピン | |
| JP6  | ピンヘッダ | 2.5mmピッチ 2ピン | |
| JP7  | ピンヘッダ | 2.5mmピッチ 2ピン | |
| JP8  | ピンヘッダ | 2.5mmピッチ 2ピン | |
| R1 | 抵抗器 | 1kΩ 1/4W 5% | |
| R2 | 抵抗器 | 1kΩ 1/4W 5% | |

### 電源モジュールの製作に必要な部品（基板外および部品番号なし）

| 部品番号 | デバイス名 | 値/型番 | 備考 |
| ---- | --- | --- | --- |
| LED1 | パネル取り付けタイプLED | | JP3から配線 |
| LED2 | パネル取り付けタイプLED | | JP4から配線 |
| SW1  | 6Pトグルスイッチ | | JP7,8から配線 |
| J3 | 3.5mmミニジャック | | JP1から配線 |
| J4 | 3.5mmミニジャック | | JP2から配線 |
| | リード線 | | |
| | スイッチングACアダプタ  | 15V、0.8A以上 | 2個必要、センタープラス |
| | ヒートシンク | LSIクーラー | H9.5×19×19 |
| | | | 1919-9 |
| | ナベ小ねじ | 3x10 | 2本必要 |
| | ナット | | 3mm |

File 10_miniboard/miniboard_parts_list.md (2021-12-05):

# MInI Board II パーツリスト

| 部品番号 | デバイス名 | 値/型番 | 備考 |
| ---- | --- | --- | --- |
| C1 | 積層セラミックコンデンサ | 0.1μF | |
| C2 | 電解コンデンサ | 100μF 25V | |
| C3 | 電解コンデンサ | 100μF 25V | |
| C4 | 積層セラミックコンデンサ | 0.1μF | |
| C5 | 積層セラミックコンデンサ | 0.1μF | |
| C6 | 積層セラミックコンデンサ | 0.1μF | |
| C7 | 電解コンデンサ | 100μF 16V | |
| C8 | セラミックコンデンサ | 27pF | |
| C9 | セラミックコンデンサ | 27pF | |
| C10  | 積層セラミックコンデンサ | 0.1μF | |
| C11  | 積層セラミックコンデンサ | 0.47μF | |
| C12  | 積層セラミックコンデンサ | 0.47μF | |
| C13  | 積層セラミックコンデンサ | 0.47μF | |
| C14  | 積層セラミックコンデンサ | 0.001μF | |
| C15  | 積層セラミックコンデンサ | 0.022μF | |
| C16  | 積層セラミックコンデンサ | 0.022μF | |
| C17  | 積層セラミックコンデンサ | 0.022μF | |
| D1 | ダイオード | 1N4148 | |
| D2 | ダイオード | 1N4148 | |
| D3 | ダイオード | 1N4148 | |
| D4 | ダイオード | 1N4148 | |
| D5 | ダイオード | 1N4148 | |
| D6 | ダイオード | 1N4148 | |
| D7 | ダイオード | 1N4148 | |
| D8 | ダイオード | 1N4148 | |
| D9 | ダイオード | 1N4148 | |
| D10  | ダイオード | 1N4148 | |
| D11  | ダイオード | 1N4148 | |
| D12  | ダイオード | 1N4148 | |
| D13  | ダイオード | 1N4148 | |
| D14  | ダイオード | 1N4148 | |
| D15  | ダイオード | 1N4148 | |
| D16  | ダイオード | 1N4148 | |
| D17  | ダイオード | 1N4148 | |
| D18  | ダイオード | 1N4148 | |
| D19  | ダイオード | 1N4148 | |
| D20  | ダイオード | 1N4148 | |
| D21  | ダイオード | 1N4148 | |
| D22  | ダイオード | 1N4148 | |
| D23  | ダイオード | 1N4148 | |
| D24  | ダイオード | 1N4148 | |
| D25  | ダイオード | 1N4148 | |
| D26  | ダイオード | 1N4148 | |
| IC1  | 三端子レギュレータ | LM78L05 | |
| IC2  | オペアンプ | TL064 | |
| IC3  | マイクロプロセッサ | ATTiny2313 | |
| J1 | コネクタ | DIN 5P 180° | MIDI入力 |
| JP1  | ボックスピンヘッダ | 2.5mm ピッチ 2x5 L字型 | Lifeline |
| JP2  | ピンヘッダ | 2.5mm ピッチ 2x3 | ISP writing port |
| Q1 | 水晶発振子 | 20MHz | |
| R1 | 抵抗器 | 22kΩ | |
| R2 | 抵抗器 | 470kΩ | |
| R3 | 抵抗器 | 10kΩ | |
| R4 | 抵抗器 | 10kΩ | |
| R5 | 抵抗器 | 10kΩ | |
| R6 | 抵抗器 | 1MΩ | |
| R8 | 抵抗器 | 56kΩ | |
| R9 | 半固定抵抗 | 20kΩ | |
| R10  | 抵抗器 | 47kΩ | |
| R11  | 抵抗器 | 820kΩ | |
| R12  | 半固定抵抗 | 500kΩ | |
| R13  | 抵抗器 | 47kΩ | |
| R14  | 抵抗器 | 1kΩ | |
| R15  | 抵抗器 | 220Ω | |
| R16  | 抵抗器 | 10kΩ | |
| R17  | 抵抗器 | 10kΩ | |
| R18  | 抵抗器 | 10kΩ | |
| R19  | 抵抗器 | 470kΩ | |
| R20  | 抵抗器 | 47kΩ | |
| R21  | 抵抗器 | 1kΩ | |
| S1 | タクトスイッチ | | 鍵盤 C# |
| S2 | タクトスイッチ | | 鍵盤 D# |
| S3 | タクトスイッチ | | 鍵盤 F# |
| S4 | タクトスイッチ | | 鍵盤 G# |
| S5 | タクトスイッチ | | 鍵盤 A# |
| S6 | タクトスイッチ | | 鍵盤 A |
| S7 | タクトスイッチ | | 鍵盤 lowC |
| S8 | タクトスイッチ | | 鍵盤 D |
| S9 | タクトスイッチ | | 鍵盤 E |
| S10  | タクトスイッチ | | 鍵盤 F |
| S11  | タクトスイッチ | | 鍵盤 G |
| S12  | タクトスイッチ | | 鍵盤 B |
| S13  | タクトスイッチ | | 鍵盤 highC |
| S14  | タクトスイッチ | | Function Switch  |
| SP1  | ピエゾスピーカ | | |
| SW1  | ロータリーDIPスイッチ | | Octave/MIDI Ch |
| U1 | フォトカプラ | TLP552 | 6N137 でも可 |

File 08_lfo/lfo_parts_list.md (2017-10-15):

# Strict Gate ControlLFO モジュールのパーツリスト

### LFOの製作に必要な部品（基板内）

| 部品番号 | デバイス名 | 値/型番 | 備考 |
| ---- | --- | --- | --- |
| C1 | 積層セラミックコンデンサ | 0.47μF | |
| C2 | 積層セラミックコンデンサ | 0.1μF | |
| C3 | 電解コンデンサ | 10μF 25V | |
| C4 | 積層セラミックコンデンサ | 0.1μF | |
| C5 | 電解コンデンサ | 100μF 25V | |
| C6 | 積層セラミックコンデンサ | 0.1μF | |
| C7 | 電解コンデンサ | 100μF 25V | |
| C8 | 積層セラミックコンデンサ | 0.1μF | |
| C9 | 積層セラミックコンデンサ | 1μF | |
| D1 | ダイオード | 1N4148 | |
| D2 | ダイオード | 1N4148 | |
| IC1  | オペアンプ | TL071 | |
| IC2  | オペアンプ | TL072 | |
| JP1  | ピンヘッダ | 2.5mmピッチ 2x1 | Strict Gate Control |
| JP2  | ピンヘッダ | 2.5mmピッチ 2x1 | Delay Out |
| JP3  | ピンヘッダ | 2.5mmピッチ 3x1 | Gate In |
| JP4  | ピンヘッダ | 2.5mmピッチ 3x1 | Delay Source |
| JP5  | ピンヘッダ | 2.5mmピッチ 5x2 L字型 | Lifeline |
| JP6  | ピンヘッダ | 2.5mmピッチ 2x1 | Triangular Out |
| JP7  | ピンヘッダ | 2.5mmピッチ 2x1 | Rectangular Out |
| Q1 | トランジスタ | 2N3906 | |
| Q2 | トランジスタ | 2N3904 | |
| Q3 | トランジスタ | 2N3904 | |
| Q4 | トランジスタ | 2N3904 | |
| R1 | 抵抗器 | 10kΩ 1/4W 5% | |
| R2 | 抵抗器 | 100kΩ 1/4W 5% | |
| R3 | 抵抗器 | 6.8kΩ 1/4W 5% | |
| R4 | 抵抗器 | 150kΩ 1/4W 5% | |
| R5 | 抵抗器 | 220Ω 1/4W 5% | |
| R6 | 抵抗器 | 1kΩ 1/4W 5% | |
| R7 | 抵抗器 | 150kΩ 1/4W 5% | |
| R8 | 抵抗器 | 10kΩ 1/4W 5% | |
| R9 | 抵抗器 | 47kΩ 1/4W 5% | |
| R10  | 可変抵抗 | 50kΩ A | Delay |
| R11  | 抵抗器 | 47kΩ 1/4W 5% | |
| R12  | 抵抗器 | 47kΩ 1/4W 5% | |
| R13  | 抵抗器 | 10kΩ 1/4W 5% | |
| R14  | 抵抗器 | 47kΩ 1/4W 5% | |
| R15  | 抵抗器 | 15kΩ 1/4W 5% | |
| R16  | 抵抗器 | 33kΩ 1/4W 5% | |
| R17  | 抵抗器 | 1kΩ 1/4W 5% | |
| R18  | 抵抗器 | 5.6kΩ 1/4W 5% | #f03c15 初版から値を変更 |
| R19  | 抵抗器 | 4.7kΩ 1/4W 5% | #f03c15 初版から値を変更 |
| R20  | 抵抗器 | 7.5kΩ 1/4W 5% | |
| R21  | 可変抵抗 | 50kΩ A | Frequency |
| R22  | 抵抗器 | 47Ω 1/4W 5% | |

### LFOの製作に必要な部品（基板外）

| 部品番号 | デバイス名 | 値/型番 | 備考 |
| ---- | --- | --- | --- |
| J1 | 3.5mm ピンジャック | | Triangular Out  |
| J2 | 3.5mm ピンジャック | | Rectangular Out |
| J3 | 3.5mm ピンジャック | スイッチつき | Trigger In |

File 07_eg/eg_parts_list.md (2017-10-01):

# エンベロープ・ジェネレータモジュールのパーツリスト

### EGの製作に必要な部品（基板内）

| 部品番号 | デバイス名 | 値/型番 | 備考 |
| ---- | --- | --- | --- |
| C1 | 積層セラミックコンデンサ | 0.001μF | セラミックコンデンサでも可 |
| C2 | 積層セラミックコンデンサ | 0.01μF | セラミックコンデンサでも可 |
| C3 | 電解コンデンサ | 100μF 25V | |
| C4 | 積層セラミックコンデンサ | 0.1μF | セラミックコンデンサでも可 |
| C5 | 電解コンデンサ | 100μF 25V | |
| C6 | 電解コンデンサ | 47μF 25V | |
| C7 | 積層セラミックコンデンサ | 0.1μF | セラミックコンデンサでも可 |
| C8 | 積層セラミックコンデンサ | 0.1μF | セラミックコンデンサでも可 |
| D2 | ダイオード | 1N4148 | |
| D3 | ダイオード | 1N4148 | |
| D4 | ダイオード | 1N4148 | |
| D5 | ダイオード | 1N4148 | |
| D6 | ダイオード | 1N4148 | |
| IC1  | タイマIC | NE555 | |
| IC2  | オペアンプ | TL072 | |
| JP1  | ピンヘッダ | 2.5mmピッチ 1x3 | Int/Ext Gate SW |
| JP2  | ピンヘッダ | 2.5mmピッチ 2x5 L字型 | Lifeline |
| JP3  | ピンヘッダ | 2.5mmピッチ 1x2 | Non-Inv Out |
| JP4  | ピンヘッダ | 2.5mmピッチ 1x2 | Inv Out |
| Q1 | トランジスタ | 2N3904 | |
| Q2 | トランジスタ | 2N3904 | |
| Q3 | トランジスタ | 2N3904 | |
| Q4 | トランジスタ | 2N3904 | |
| Q5 | トランジスタ | 2N3904 | |
| Q6 | トランジスタ | 2N3906 | |
| R1 | 抵抗器 | 24kΩ | 1/4W 5% |
| R2 | 抵抗器 | 2.2kΩ | 1/4W 5% |
| R3 | 可変抵抗 | 50kΩ A | |
| R4 | 抵抗器 | 2.2kΩ | 1/4W 5% |
| R5 | 抵抗器 | 4.7kΩ | 1/4W 5% |
| R6 | 抵抗器 | 2.2kΩ | 1/4W 5% |
| R7 | 可変抵抗 | 50kΩ A | |
| R8 | 抵抗器 | 10kΩ | 1/4W 5% |
| R9 | 抵抗器 | 10kΩ | 1/4W 5% |
| R10  | 抵抗器 | 10kΩ | 1/4W 5% |
| R11  | 抵抗器 | 47kΩ | 1/4W 5% |
| R12  | 抵抗器 | 2.2kΩ | 1/4W 5% |
| R13  | 抵抗器 | 22kΩ | 1/4W 5% |
| R14  | 抵抗器 | 100kΩ | 1/4W 5% |
| R15  | 可変抵抗 | 50kΩ A | |
| R16  | 抵抗器 | 100kΩ | 1/4W 5% |
| R17  | 抵抗器 | 1kΩ | 1/4W 5% |
| R18  | 可変抵抗 | 50kΩ A | |
| R19  | 抵抗器 | 47kΩ | 1/4W 5% |
| R20  | 抵抗器 | 1kΩ | 1/4W 5% |
| R21  | 抵抗器 | 1kΩ | 1/4W 5%、#f03c15 改訂版で追加 |

### EGの製作に必要な部品（基板外）

| 部品番号 | デバイス名 | 値/型番 | 備考 |
| ---- | --- | --- | --- |
| J1 | 3.5mm ピンジャック | Non-Inv Out | |
| J2 | 3.5mm ピンジャック | Inv Out | |
| J3 | 3.5mm ピンジャック | スイッチつき | Gate In |

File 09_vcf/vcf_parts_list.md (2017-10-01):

# VCF モジュールのパーツリスト

### VCFの製作に必要な部品（基板内）

| 部品番号 | デバイス名 | 値/型番 | 備考 |
| ---- | --- | --- | --- |
| C1 | 電解コンデンサ | 100μF 25V | |
| C2 | 電解コンデンサ | 100μF 25V | |
| C3 | ポリプロピレンコンデンサ | 0.068μF | |
| C4 | ポリエステルコンデンサ  | 0.1μF | |
| C5 | ポリエステルコンデンサ  | 0.1μF | |
| C6 | ポリプロピレンコンデンサ | 0.068μF | |
| C7 | 電解コンデンサ | 10μF 25V | |
| C8 | ポリプロピレンコンデンサ | 0.068μF | |
| C9 | ポリプロピレンコンデンサ | 0.068μF | |
| C10  | 電解コンデンサ | 10μF 25V | |
| C11  | 電解コンデンサ | 220μF 25V | |
| C12  | 電解コンデンサ | 100μF 25V | |
| C13  | 積層セラミックコンデンサ | 0.1μF | |
| C14  | セラミックコンデンサ | 100pF | |
| C15  | 電解コンデンサ | 100μF 25V | |
| C16  | 積層セラミックコンデンサ | 0.1μF | |
| IC1  | オペアンプ | TL072 | |
| JP1  | ピンヘッダ | 2.5mmピッチ 1x2 | Audio Out |
| JP2  | ピンヘッダ | 2.5mmピッチ 1x2 | CV In |
| JP3  | ピンヘッダ | 2.5mmピッチ 1x2 | Envelope In |
| JP4  | ピンヘッダ | 2.5mmピッチ 1x2 | Audio In |
| JP5  | ピンヘッダ | 2.5mmピッチ 1x3 | Keyboard Track |
| JP6  | ピンヘッダ | 2.5mmピッチ 2x5 L字型 | Lifeline |
| Q1 | トランジスタ | 2N3904 | |
| Q2 | トランジスタ | 2N3904 | |
| Q3 | トランジスタ | 2N3904 | |
| Q4 | トランジスタ | 2N3904 | |
| Q5 | トランジスタ | 2N3904 | |
| Q6 | トランジスタ | 2N3904 | |
| Q7 | トランジスタ | 2N3904 | |
| Q8 | トランジスタ | 2N3904 | |
| Q9 | トランジスタ | 2N3904 | |
| Q10  | トランジスタ | 2N3904 | |
| Q11  | トランジスタ | 2N3904 | |
| Q12  | トランジスタ | 2N3904 | |
| Q13  | トランジスタ | 2N3904 | |
| Q14  | トランジスタ | 2N3904 | |
| Q15  | トランジスタ | 2N3904 | |
| Q16  | トランジスタ | 2N3904 | |
| Q17  | トランジスタ       | 2N3904           | #f03c15 改訂版で追加 |
| R1 | 抵抗器 | 470kΩ | 1/4W 5% |
| R2 | 抵抗器 | 47Ω | 1/4W 5% |
| R3 | 抵抗器 | 390Ω | 1/4W 5% |
| R4 | 抵抗器 | 180Ω | 1/4W 5% |
| R5 | 抵抗器 | 150Ω | 1/4W 5% |
| R6 | 抵抗器 | 220kΩ | 1/4W 5% |
| R7 | 抵抗器 | 1kΩ | 1/4W 5% |
| R8 | 抵抗器 | 150Ω | 1/4W 5% |
| R9 | 抵抗器 | 100kΩ | 1/4W 5% |
| R10  | 抵抗器 | 150Ω | 1/4W 5% |
| R11  | 抵抗器 | 100kΩ | 1/4W 5% |
| R12  | 抵抗器 | 100kΩ | 1/4W 5% |
| R13  | 抵抗器 | 100kΩ | 1/4W 5% |
| R14  | 抵抗器 | 680Ω | 1/4W 5% |
| R15  | 抵抗器 | 100kΩ | 1/4W 5% |
| R16  | 抵抗器 | 150Ω | 1/4W 5% |
| R17  | 抵抗器 | 6.8kΩ | 1/4W 5% |
| R18  | 抵抗器 | 47kΩ | 1/4W 5% |
| R19  | 半固定抵抗 | 10kΩ | |
| R20  | 抵抗器 | 220kΩ | 1/4W 5% |
| R21  | 抵抗器 | 330Ω | 1/4W 5% |
| R22  | 半固定抵抗 | 1kΩ | |
| R23  | 抵抗器 | 200Ω | 1/4W 5% |
| R24  | 抵抗器 | 680Ω | 1/4W 5% |
| R25  | 抵抗器 | 68kΩ | 1/4W 5% |
| R26  | 抵抗器 | 220kΩ | 1/4W 5% |
| R27  | 抵抗器 | 100kΩ | 1/4W 5% |
| R28  | 抵抗器 | 220kΩ | 1/4W 5% |
| R29  | 多回転型半固定抵抗 | 5kΩ | |
| R30  | 抵抗器 | 22kΩ | 1/4W 5% |
| R31  | 抵抗器 | 1kΩ | 1/4W 5% |
| R32  | 抵抗器 | 330Ω | 1/4W 5% |
| R33  | 抵抗器          | 4.7kΩ            | 1/4W 5%、#f03c15 改訂版で追加  |
| R34  | 抵抗器 | 1kΩ | 1/4W 5%、#f03c15 改訂版で追加  |
| VR1  | ボリューム | 50kΩ B | |
| VR2  | ボリューム | 50kΩ A | |
| VR3  | ボリューム | 50kΩ A | |
| VR4  | ボリューム | 50kΩ B | |

### VCFの製作に必要な部品（基板外）

| 部品番号 | デバイス名 | 値/型番 | 備考 |
| ---- | --- | --- | --- |
| J1 | 3.5 mmジャック | | Audio Out |
| J2 | 3.5 mmジャック | スイッチつき | CV In |
| J3 | 3.5 mmジャック | スイッチつき | Audio In  |
| SW1  | トグルスイッチ ON-OFF-ON | 中立OFFタイプ | KBD Track |

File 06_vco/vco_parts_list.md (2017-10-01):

# VCO モジュールのパーツリスト

### VCOの製作に必要な部品（基板内）

| 部品番号  | デバイス名 | 値/型番 | 備考 |
| ----- | --- | --- | --- |
| C1 | 電解コンデンサ | 10μF | 耐圧25V以上 |
| C2 | 電解コンデンサ | 100μF | 耐圧25V以上 |
| C3 | ポリプロピレンコンデンサ | 0.01μF | |
| C4 | セラミックコンデンサ | 100pF | |
| C5 | セラミックコンデンサ | 56pF | |
| C6 | 積層セラミックコンデンサ | 1.5μF | |
| C7 | セラミックコンデンサ | 100pF | |
| C8 | 積層セラミックコンデンサ | 0.1μF | |
| C9 | 電解コンデンサ | 100μF | 耐圧25V以上 |
| C10 | 積層セラミックコンデンサ | 0.1μF | |
| C11 | 積層セラミックコンデンサ | 0.1μF | |
| C12 | 積層セラミックコンデンサ | 0.1μF | |
| C13 | 電解コンデンサ | 100μF | 耐圧25V以上 |
| C14 | 積層セラミックコンデンサ | 0.1μF | |
| C15 | 積層セラミックコンデンサ | 0.1μF | |
| C16 | 積層セラミックコンデンサ | 0.1μF | |
| C17 | 積層セラミックコンデンサ | 0.1μF | |
| D1 | ダイオード | 1N4148 | |
| IC1 | オペアンプ | TL072 | |
| IC2 | オペアンプ | TL072 | |
| IC3 | オペアンプ | TL072 | |
| IC4 | オペアンプ | TL071 | |
| JP1 | ピンヘッダ | 2.5mmピッチ 1x2 | Sync In（option） |
| JP2 | ピンヘッダ | 2.5mmピッチ 1x2 | Pitch Mod, |
| JP3 | ピンヘッダ | 2.5mmピッチ 1x3 | Range Volume |
| JP4 | ピンヘッダ | 2.5mmピッチ 2 | Linear FM（option） |
| JP5 | ピンヘッダ | 2.5mmピッチ 1x2 | Master Tune Out（option） |
| JP6 | ピンヘッダ | 2.5mmピッチ 1x2 | Triangular Out |
| JP7 | ピンヘッダ | 2.5mmピッチ 1x2 | Sawtooth Out |
| JP8 | ピンヘッダ | 2.5mmピッチ 1x2 | PWM In |
| JP9 | ピンヘッダ | 2.5mmピッチ 1x2 | Pulse Out |
| JP10  | ピンヘッダ | 2.5mmピッチ 2x5 L字型 | Lifeline |
| Q1 | トランジスタ | 2N3906 | |
| Q2 | トランジスタ | 2N3904 | |
| Q3 | トランジスタ | 2N3904 | |
| Q4 | トランジスタ | 2N3904 | |
| Q5 | トランジスタ | 2N3904 | |
| R1 | 抵抗器 | 180kΩ | 1/4W 5% |
| R2 | 抵抗器 | 130kΩ | 1/4W 5% |
| R3 | 抵抗器 | 100kΩ | 1/4W 5% |
| R4 | 抵抗器 | 22kΩ | 1/4W 5% |
| R5 | 抵抗器 | 470kΩ | 1/4W 5% |
| R6 | 抵抗器 | 39kΩ | 1/4W 5% |
| R7 | 抵抗器 | 100kΩ | 1/4W 5% |
| R8 | 抵抗器 | 150Ω | 1/4W 5% |
| R9 | 抵抗器 | 150kΩ | 1/4W 5% |
| R10 | 抵抗器 | 10kΩ | 1/4W 5% |
| R11 | 抵抗器 | 470kΩ | 1/4W 5% |
| R12 | 抵抗器 | 680Ω | 1/4W 5% |
| R13 | 抵抗器 | 100kΩ | 1/4W 5% |
| R14 | 抵抗器 | 100kΩ | 1/4W 5% |
| R15 | 抵抗器 | 10kΩ | 1/4W 5% |
| R16 | 抵抗器 | 39kΩ | 1/4W 5% |
| R17 | 抵抗器 | 470kΩ | 1/4W 5% |
| R18 | 抵抗器 | 100kΩ | 1/4W 5% |
| R19 | 抵抗器 | 100kΩ | 1/4W 5% |
| R20 | 抵抗器 | 270kΩ | 1/4W 5% |
| R21 | 抵抗器 | 100kΩ | 1/4W 5% |
| R22 | 抵抗器 | 120kΩ | 1/4W 5% |
| R23 | 抵抗器 | 470kΩ | 1/4W 5% |
| R24 | 抵抗器 | 2.2kΩ | 1/4W 5% |
| R25 | 抵抗器 | 2.2kΩ | 1/4W 5% |
| R26 | 抵抗器 | 270kΩ | 1/4W 5% |
| R27 | 抵抗器 | 470kΩ | 1/4W 5% |
| R28 | 抵抗器 | 47kΩ | 1/4W 5% |
| R29 | 抵抗器 | 10kΩ | 1/4W 5% |
| R30 | 温度補償抵抗 | 1kΩ | 3300 ppm/℃ |
| R31 | 抵抗器 | 1kΩ | 1/4W 5% |
| R32 | 抵抗器 | 470kΩ | 1/4W 5% |
| R33 | 抵抗器 | 2kΩ | 1/4W 5% |
| R34 | 抵抗器 | 220kΩ | 1/4W 5% |
| R35 | 抵抗器 | 2.2kΩ | 1/4W 5% |
| R36 | 抵抗器 | 2.2MΩ | 1/4W 5% |
| R37 | 抵抗器 | 68kΩ | 1/4W 5% |
| R38 | 抵抗器 | 1kΩ | 1/4W 5% |
| TRIM1 | 多回転型半固定抵抗 | 10kΩ | |
| TRIM2 | 半固定抵抗 | 5kΩ | |
| TRIM3 | 多回転型半固定抵抗 | 5kΩ | |
| TRIM4 | 多回転型半固定抵抗 | 20kΩ | |
| VR1 | 可変抵抗 | 50kΩA | |
| VR2 | 可変抵抗 | 50kΩB | |
| VR3 | 可変抵抗 | 50kΩA | |
| VR4 | 可変抵抗 | 50kΩB | |

### VCOの製作に必要な部品（基板外）

| 部品番号 | デバイス名 | 値/型番 | 備考 |
| ---- | --- | --- | --- |
| VR5  | 可変抵抗 | 50kΩB  | Range |
| J1 | 3.5mmミニジャック | スイッチつき | Mod. In |
| J2 | 3.5mmミニジャック | | Triangular Out  |
| J3 | 3.5mmミニジャック | | Sawtooth Out |
| J4 | 3.5mmミニジャック | | Pulse Out |
| J5 | 3.5mmミニジャック | スイッチつき | PWM In |
| SW1  | ロータリースイッチ | 3接点 | Waveform Select |

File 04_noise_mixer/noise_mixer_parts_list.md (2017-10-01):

# ノイズ & ミキサー モジュールのパーツリスト

### ノイズ & ミキサーモジュールの製作に必要な部品（基板内）

| 部品番号 | デバイス名 | 値/型番 | 備考 |
| ---- | --- | --- | --- |
| C1 | 積層セラミックコンデンサ | 0.1μF | |
| C2 | 積層セラミックコンデンサ | 0.1μF | |
| C3 | ポリエステルコンデンサ  | 0.001μF | |
| C4 | ポリエステルコンデンサ  | 0.01μF | |
| C5 | 電解コンデンサ | 10μF 25V | |
| C6 | 電解コンデンサ | 100μF 25V | |
| C7 | 電解コンデンサ | 47μF 25V | |
| C8 | ポリエステルコンデンサ  | 0.1μF | |
| C9 | ポリエステルコンデンサ  | 0.1μF | |
| C10  | 電解コンデンサ | 100μF 25V | |
| C11  | セラミックコンデンサ | 47pF | |
| C12  | ポリエステルコンデンサ  | 0.0033μF | |
| C13  | 積層セラミックコンデンサ | 0.1μF | |
| C14  | 電解コンデンサ | 47μF 25V | |
| C15  | 積層セラミックコンデンサ | 0.1μF | |
| D1 | ダイオード | 1N4148 | |
| D2 | ダイオード | 1N4148 | |
| IC1  | オペアンプ | TL072 | |
| IC2  | オペアンプ | TL072 | |
| JP1  | ピンヘッダ | 2.5mmピッチ 2P | ch 1 (VCO) |
| JP2  | ピンヘッダ | 1P | inv out (option)  |
| JP3  | ピンヘッダ | 2.5mmピッチ 2P | ch 3 (Ext In) |
| JP4  | ピンヘッダ | 2.5mmピッチ 2P | Mixer Out |
| JP5  | ピンヘッダ | 2.5mmピッチ 2P | ch 2 (noise) |
| JP6  | ピンヘッダ | 2.5mmピッチ 3P | To noise selector |
| JP7  | ボックスピンヘッダ | 2.5mmピッチ 2x5P L字型 | Lifeline |
| JP8  | ピンヘッダ | 2.5mmピッチ 2P | Pink Noise Out |
| JP9  | ピンヘッダ | 2.5mmピッチ 2P | White Noise Out |
| Q1 | トランジスタ | BC547 | |
| Q2 | トランジスタ | 2N3906 | |
| R1 | 可変抵抗 | 50kΩA | |
| R2 | 抵抗器 1/4W 5%  | 100kΩ | |
| R3 | 抵抗器 1/4W 5%  | 100kΩ | |
| R4 | 抵抗器 1/4W 5%  | 100kΩ | |
| R5 | 抵抗器 1/4W 5%  | 100kΩ | |
| R6 | 抵抗器 1/4W 5%  | 1.5kΩ | |
| R7 | 可変抵抗 | 50kΩ A | |
| R8 | 抵抗器 1/4W 5%  | 100kΩ | |
| R9 | 可変抵抗 | 50kΩ A | |
| R10  | 抵抗器 1/4W 5%  | 100kΩ | |
| R11  | 抵抗器 1/4W 5%  | 10kΩ | |
| R12  | 抵抗器 1/4W 5%  | 220kΩ | |
| R13  | 抵抗器 1/4W 5%  | 33kΩ | |
| R14  | 抵抗器 1/4W 5%  | 1MΩ | |
| R15  | 抵抗器 1/4W 5%  | 1MΩ | |
| R16  | 抵抗器 1/4W 5%  | 1.5kΩ | |
| R17  | 抵抗器 1/4W 5%  | 100kΩ | |
| R18  | 抵抗器 1/4W 5%  | 1.5kΩ | |
| R19  | 抵抗器 1/4W 5%  | 2.2kΩ | |
| R20  | 抵抗器 1/4W 5%  | 100kΩ | |
| R21  | 抵抗器 1/4W 5%  | 100kΩ | |
| R22  | 抵抗器 1/4W 5%  | 100kΩ | |
| R23  | 抵抗器 1/4W 5%  | 4.7kΩ | |
| R24  | 半固定抵抗 | 50kΩ | |
| R25  | 抵抗器 1/4W 5%  | 2.2kΩ | |
| R26  | 抵抗器 1/4W 5%  | 10kΩ | |

### ノイズ・ミキサーモジュールの製作に必要な部品（基板外）

| 部品番号 | デバイス名 | 値/型番 | 備考 |
| ---- | --- | ---- | --- |
| J1 | 3.5mm ジャック | | Ext In |
| J2 | 3.5mm ジャック | | Mixer Out |
| J3 | 3.5mm ジャック | | White Noise Out |
| J4 | 3.5mm ジャック | | Pink Noise Out |
| SW1  | 3P トグルスイッチ | | white/pink noise selector |

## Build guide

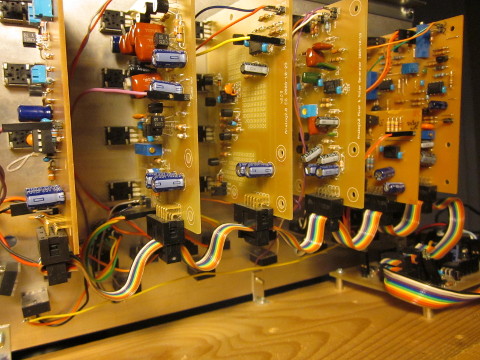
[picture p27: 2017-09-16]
01_overview/wiring1_s.jpg

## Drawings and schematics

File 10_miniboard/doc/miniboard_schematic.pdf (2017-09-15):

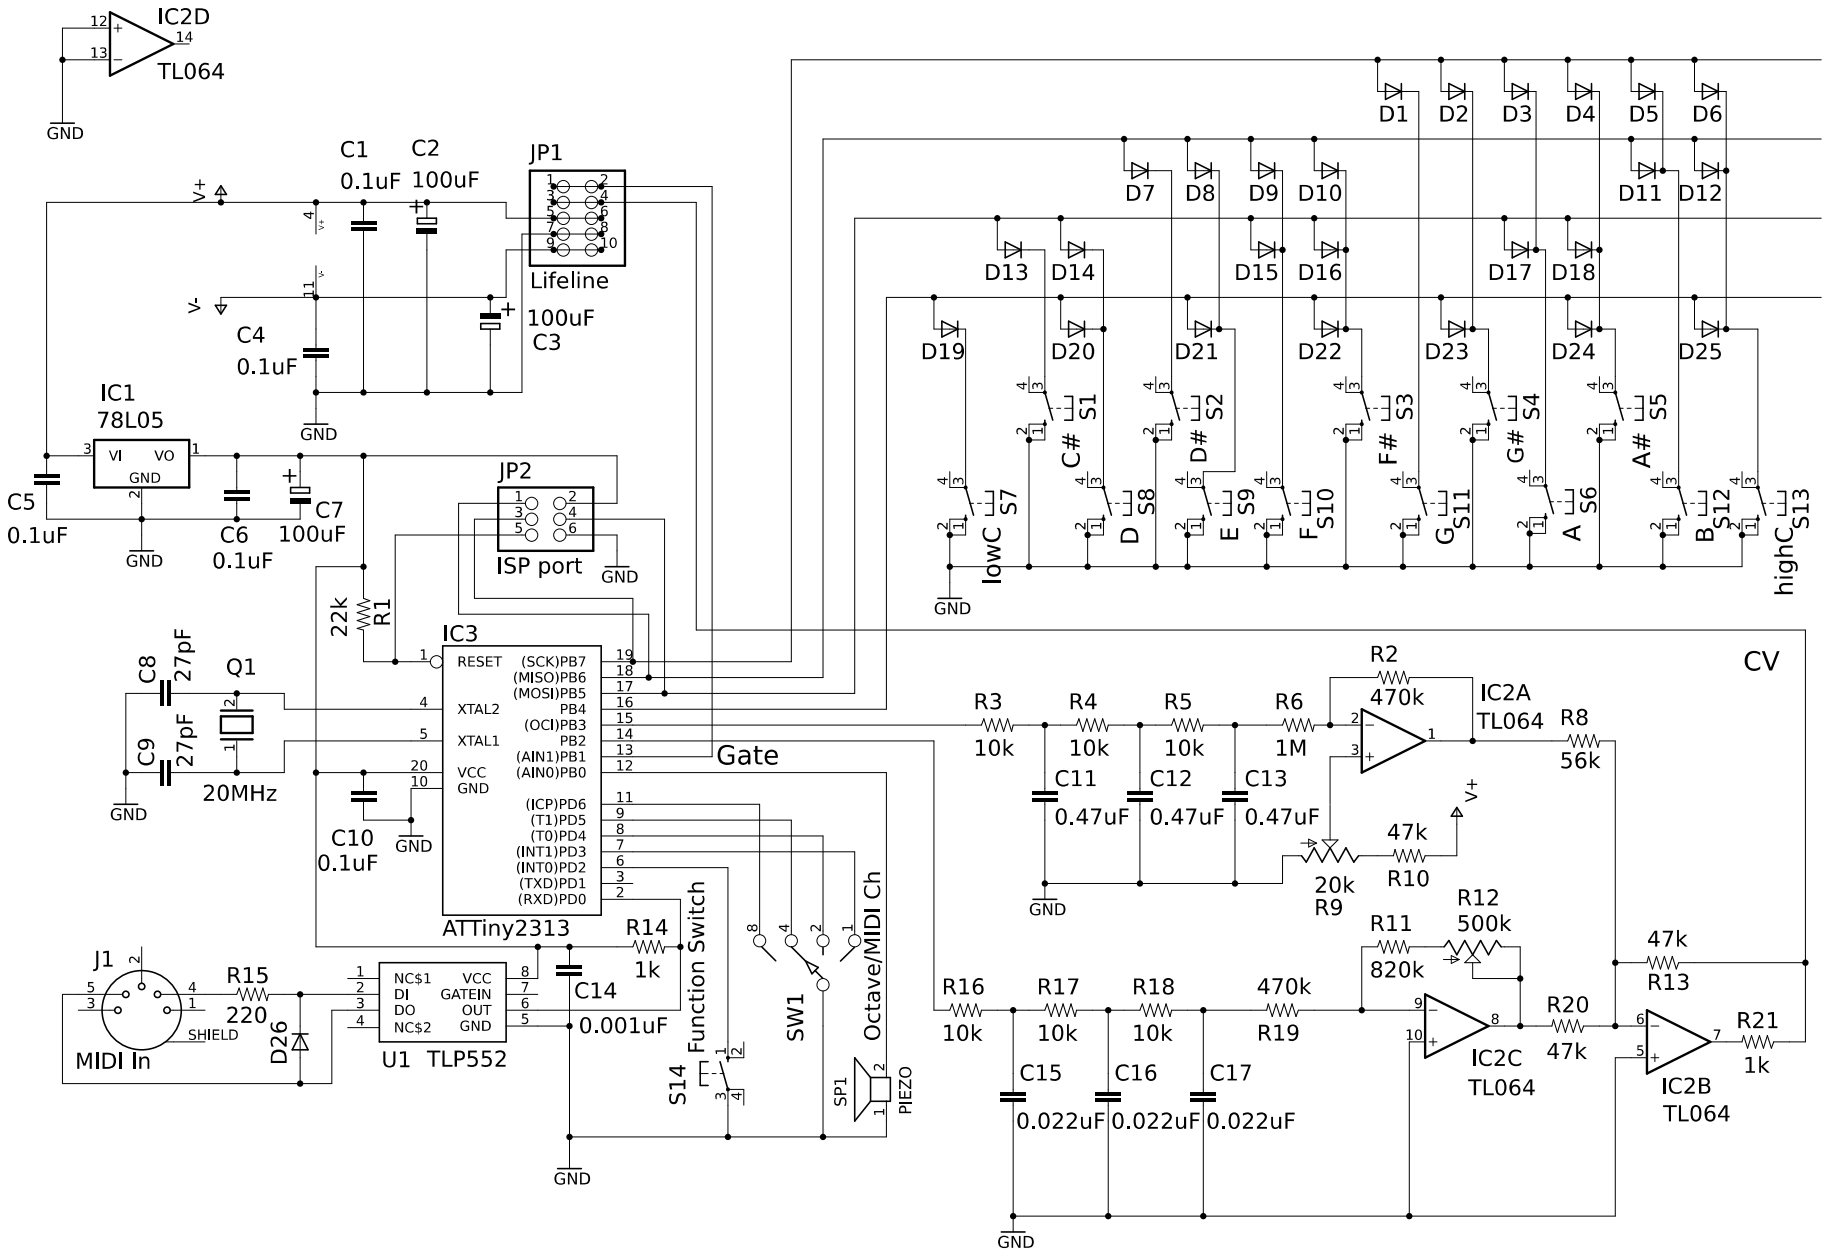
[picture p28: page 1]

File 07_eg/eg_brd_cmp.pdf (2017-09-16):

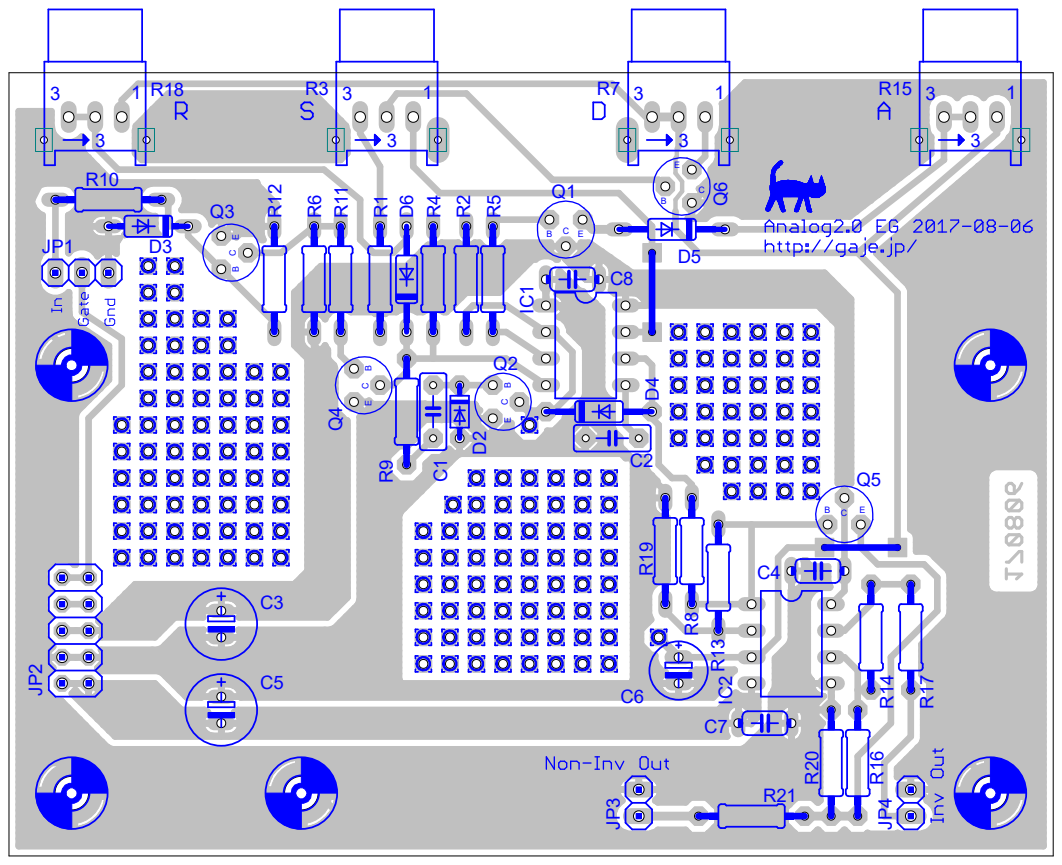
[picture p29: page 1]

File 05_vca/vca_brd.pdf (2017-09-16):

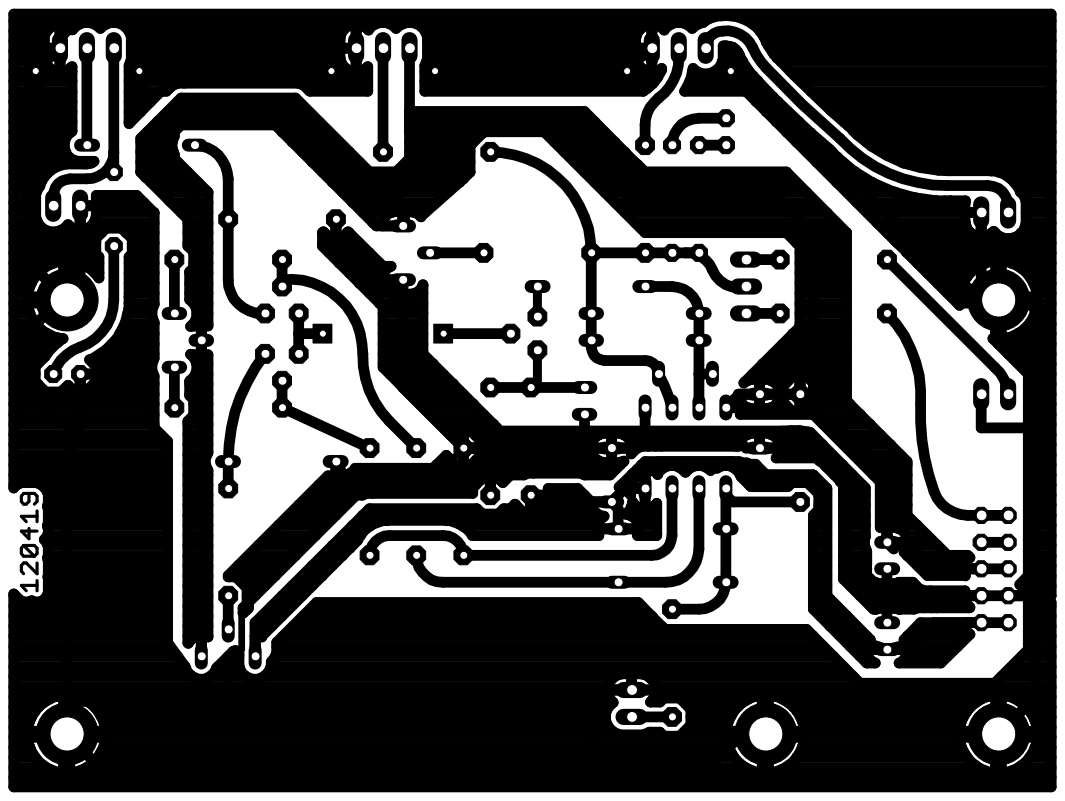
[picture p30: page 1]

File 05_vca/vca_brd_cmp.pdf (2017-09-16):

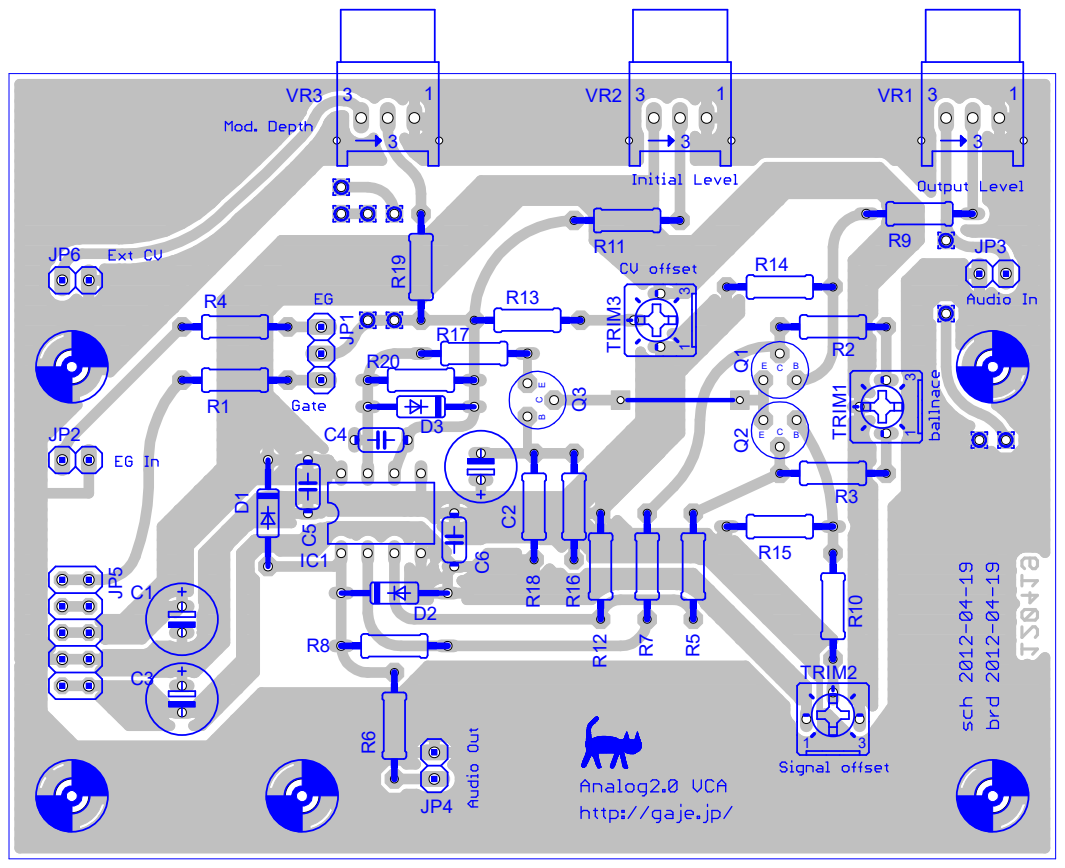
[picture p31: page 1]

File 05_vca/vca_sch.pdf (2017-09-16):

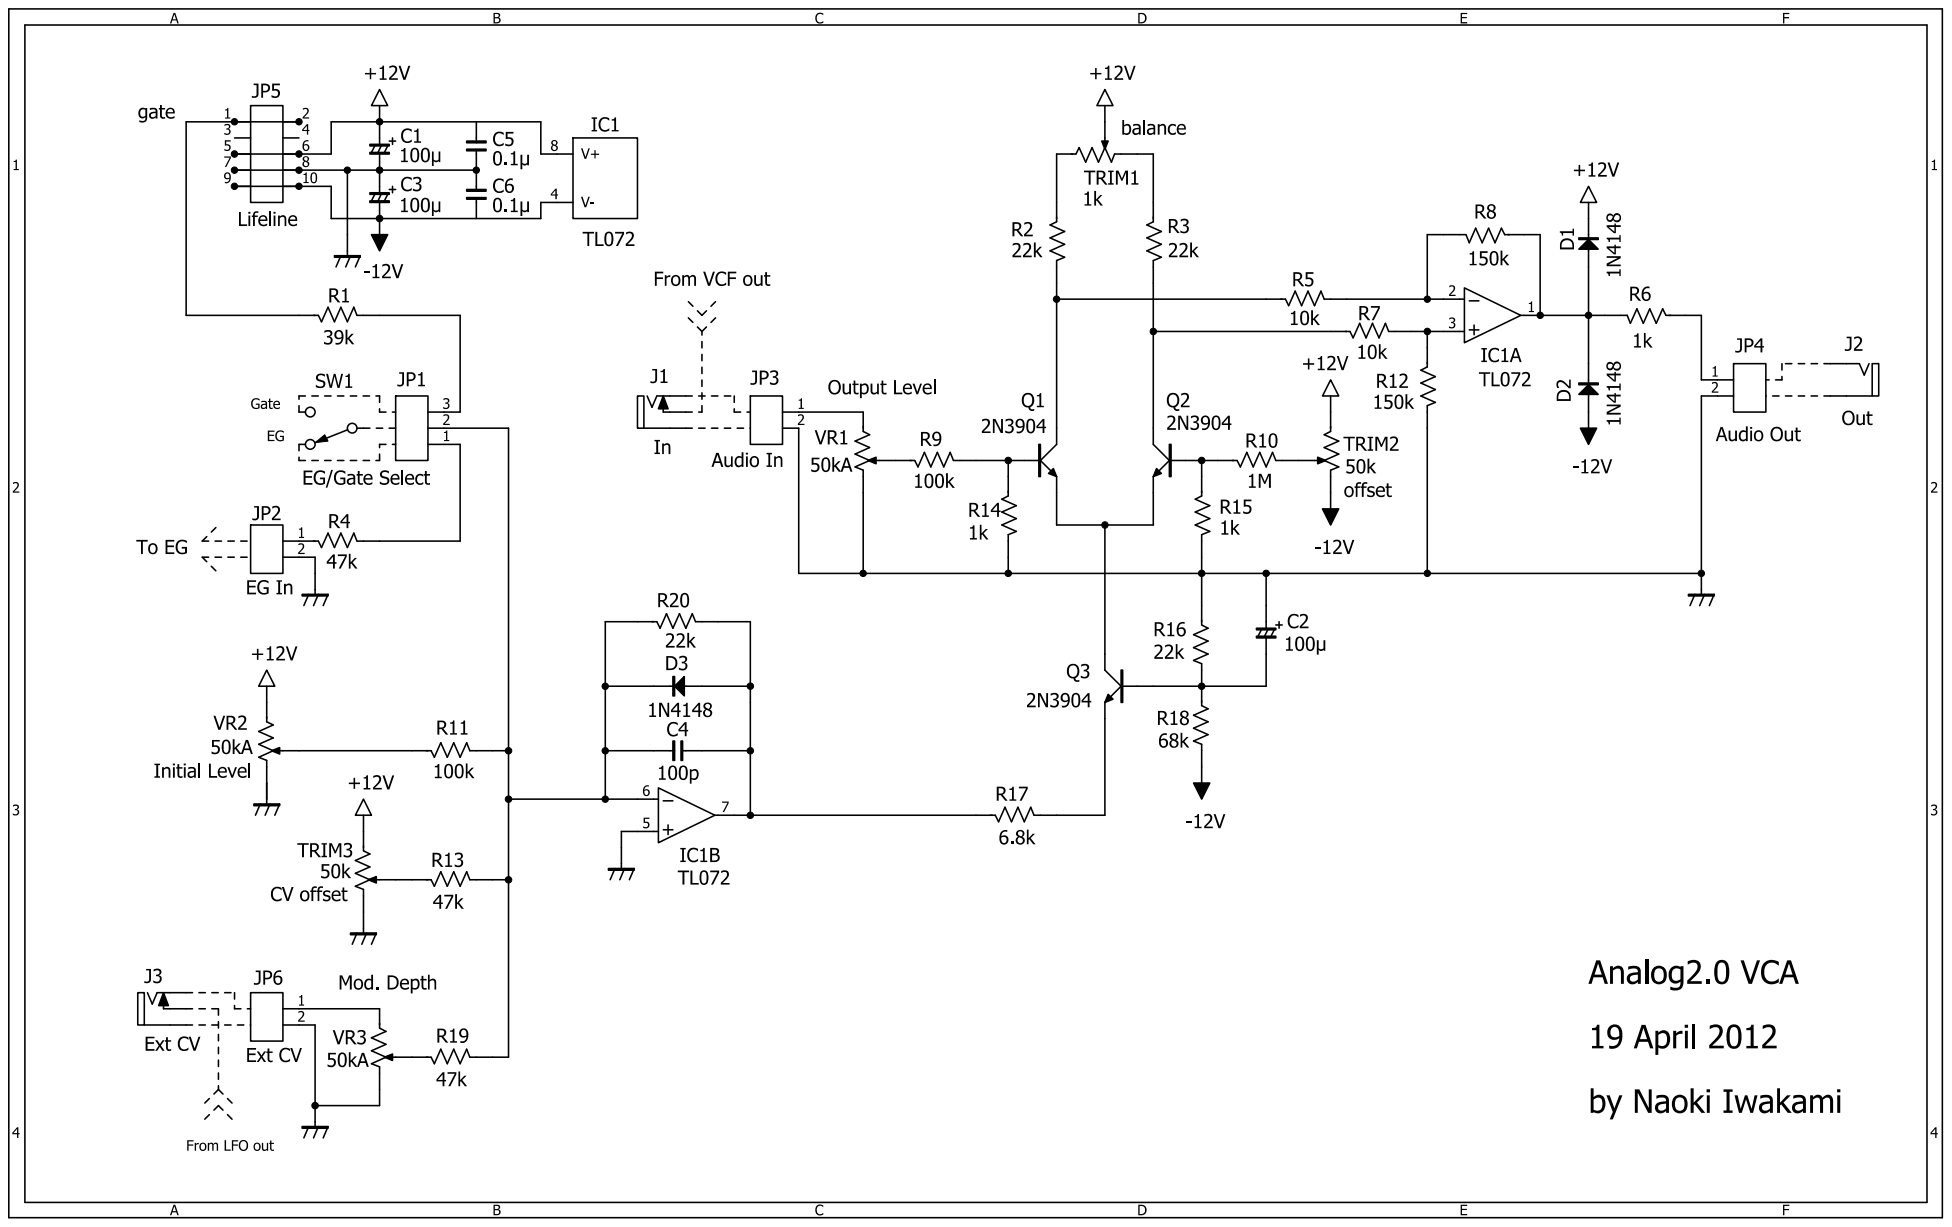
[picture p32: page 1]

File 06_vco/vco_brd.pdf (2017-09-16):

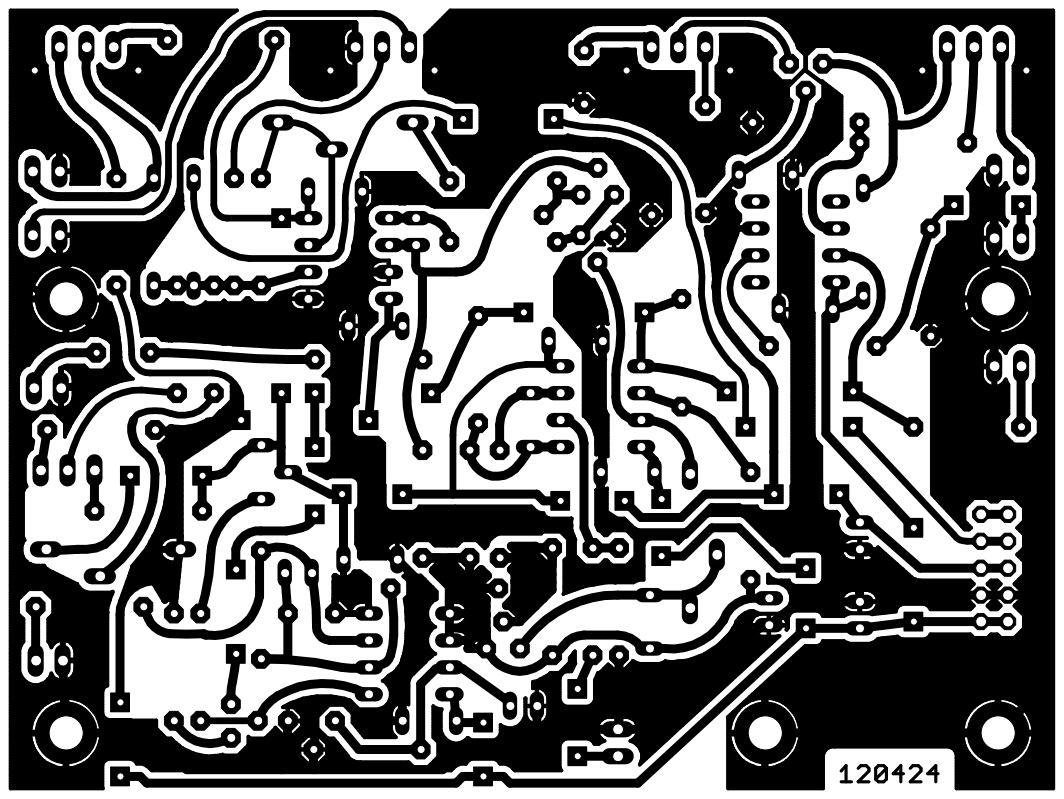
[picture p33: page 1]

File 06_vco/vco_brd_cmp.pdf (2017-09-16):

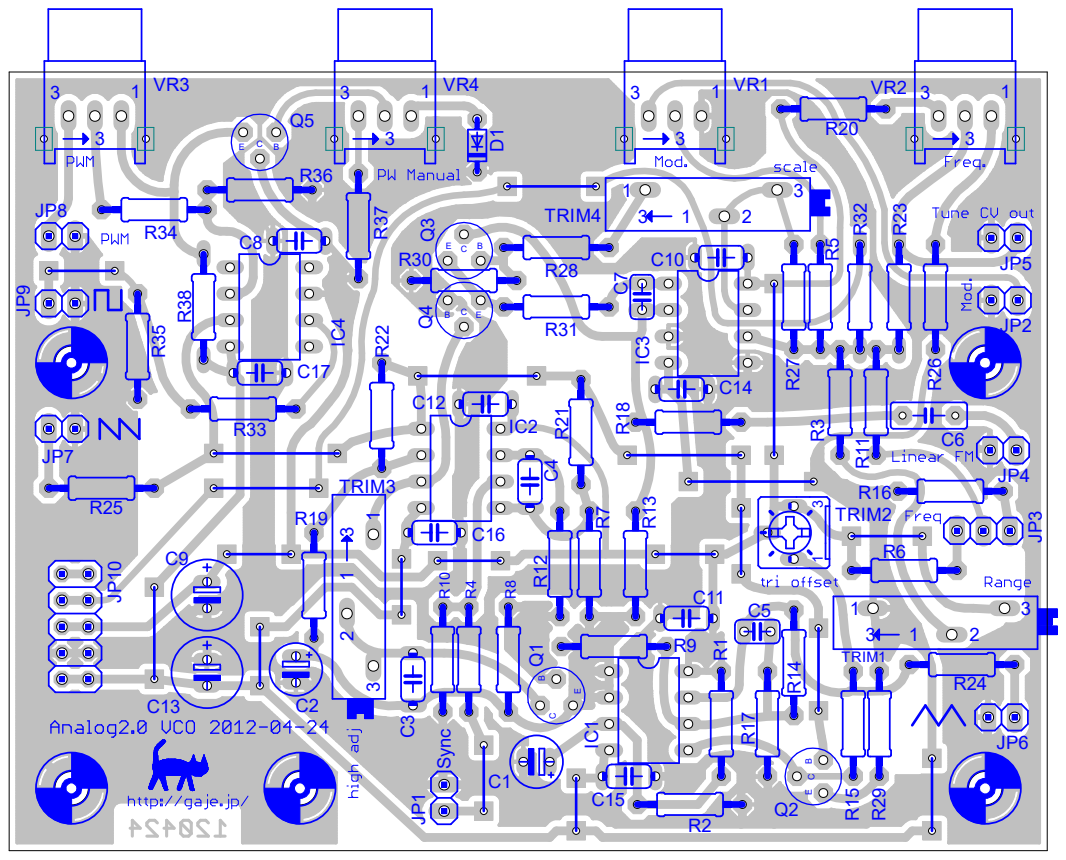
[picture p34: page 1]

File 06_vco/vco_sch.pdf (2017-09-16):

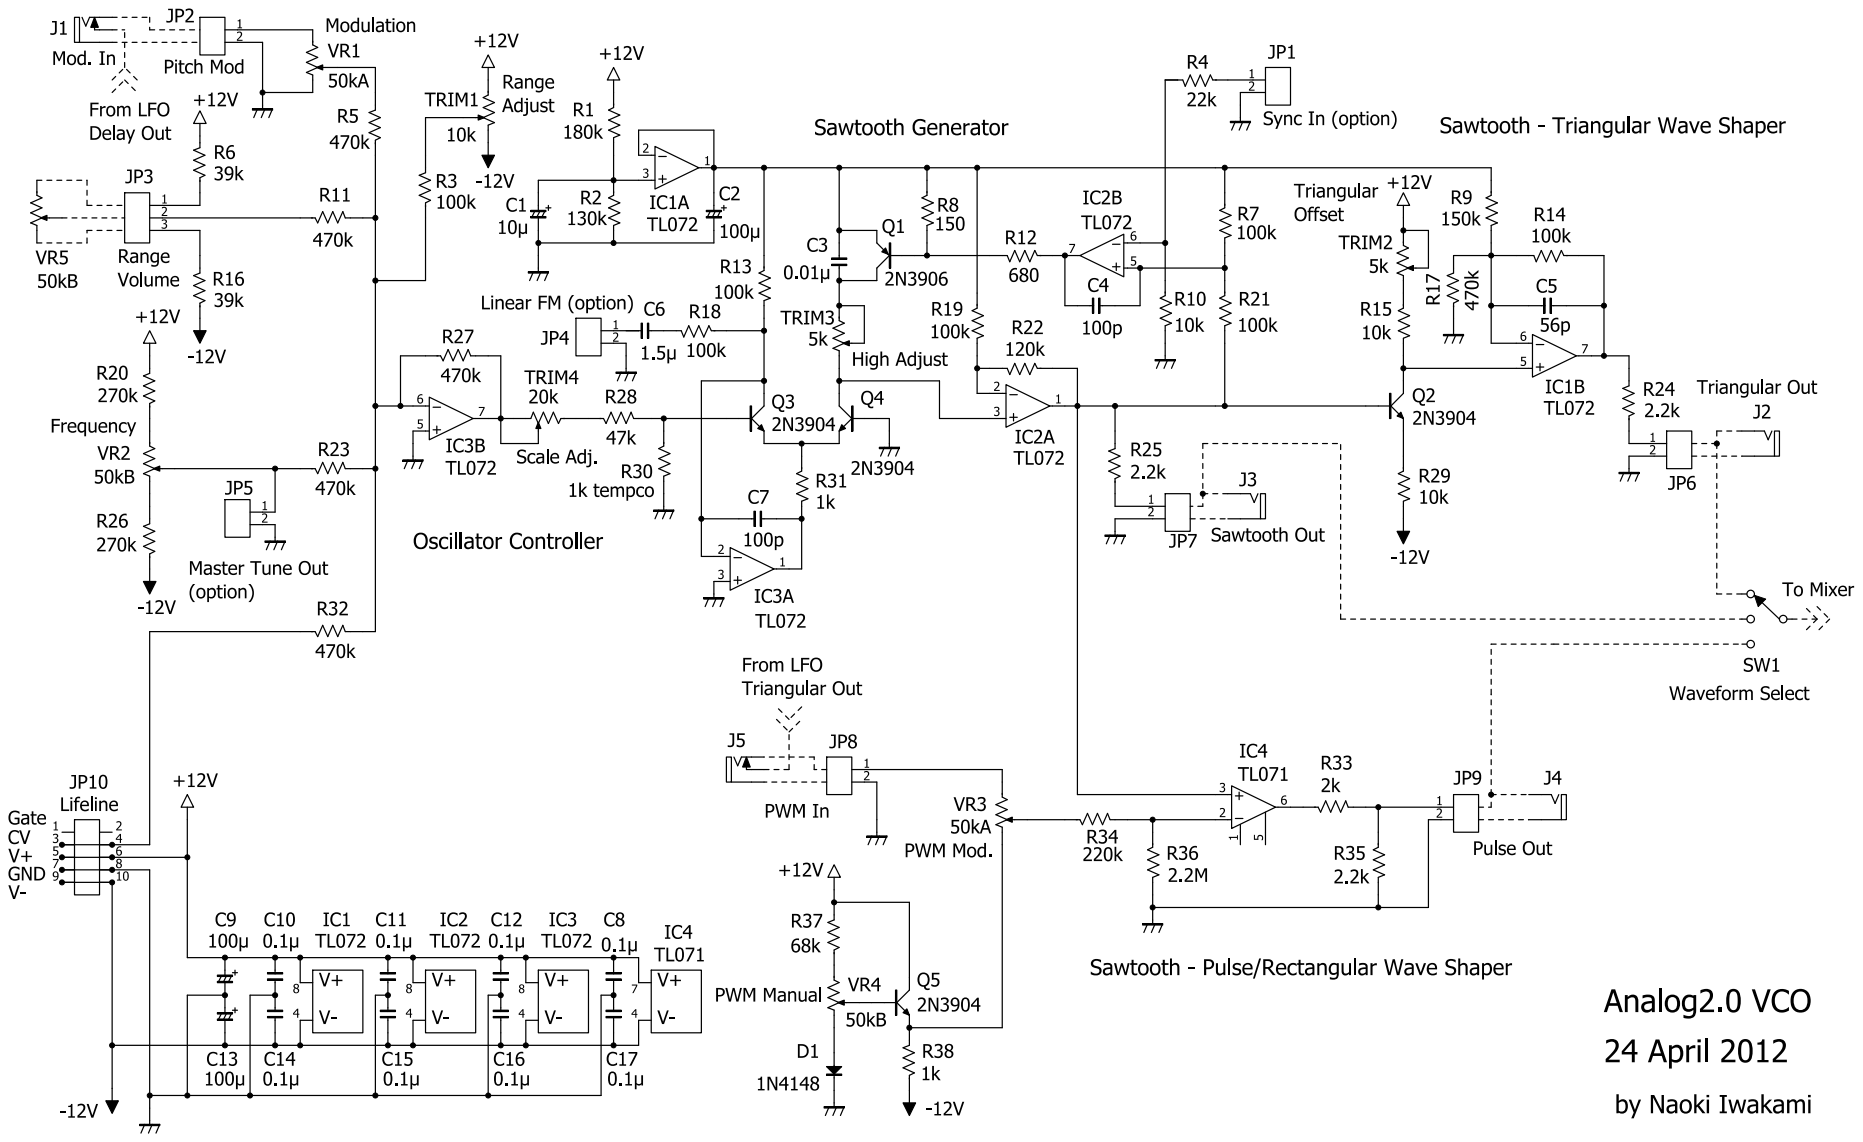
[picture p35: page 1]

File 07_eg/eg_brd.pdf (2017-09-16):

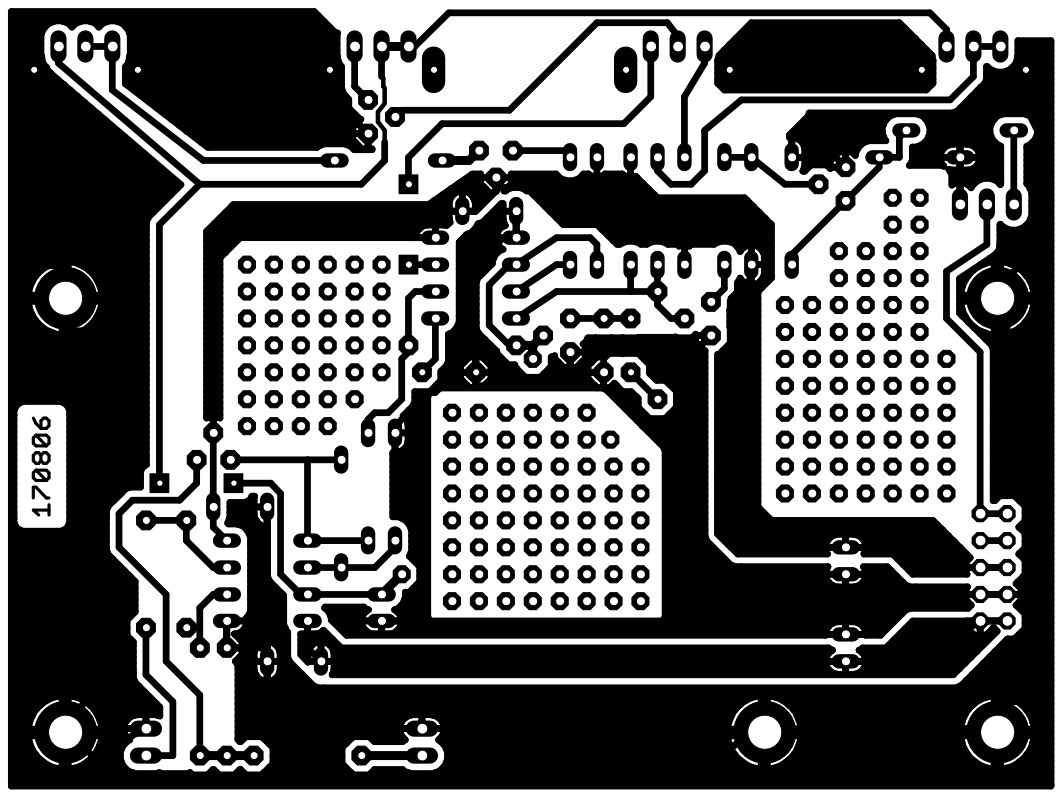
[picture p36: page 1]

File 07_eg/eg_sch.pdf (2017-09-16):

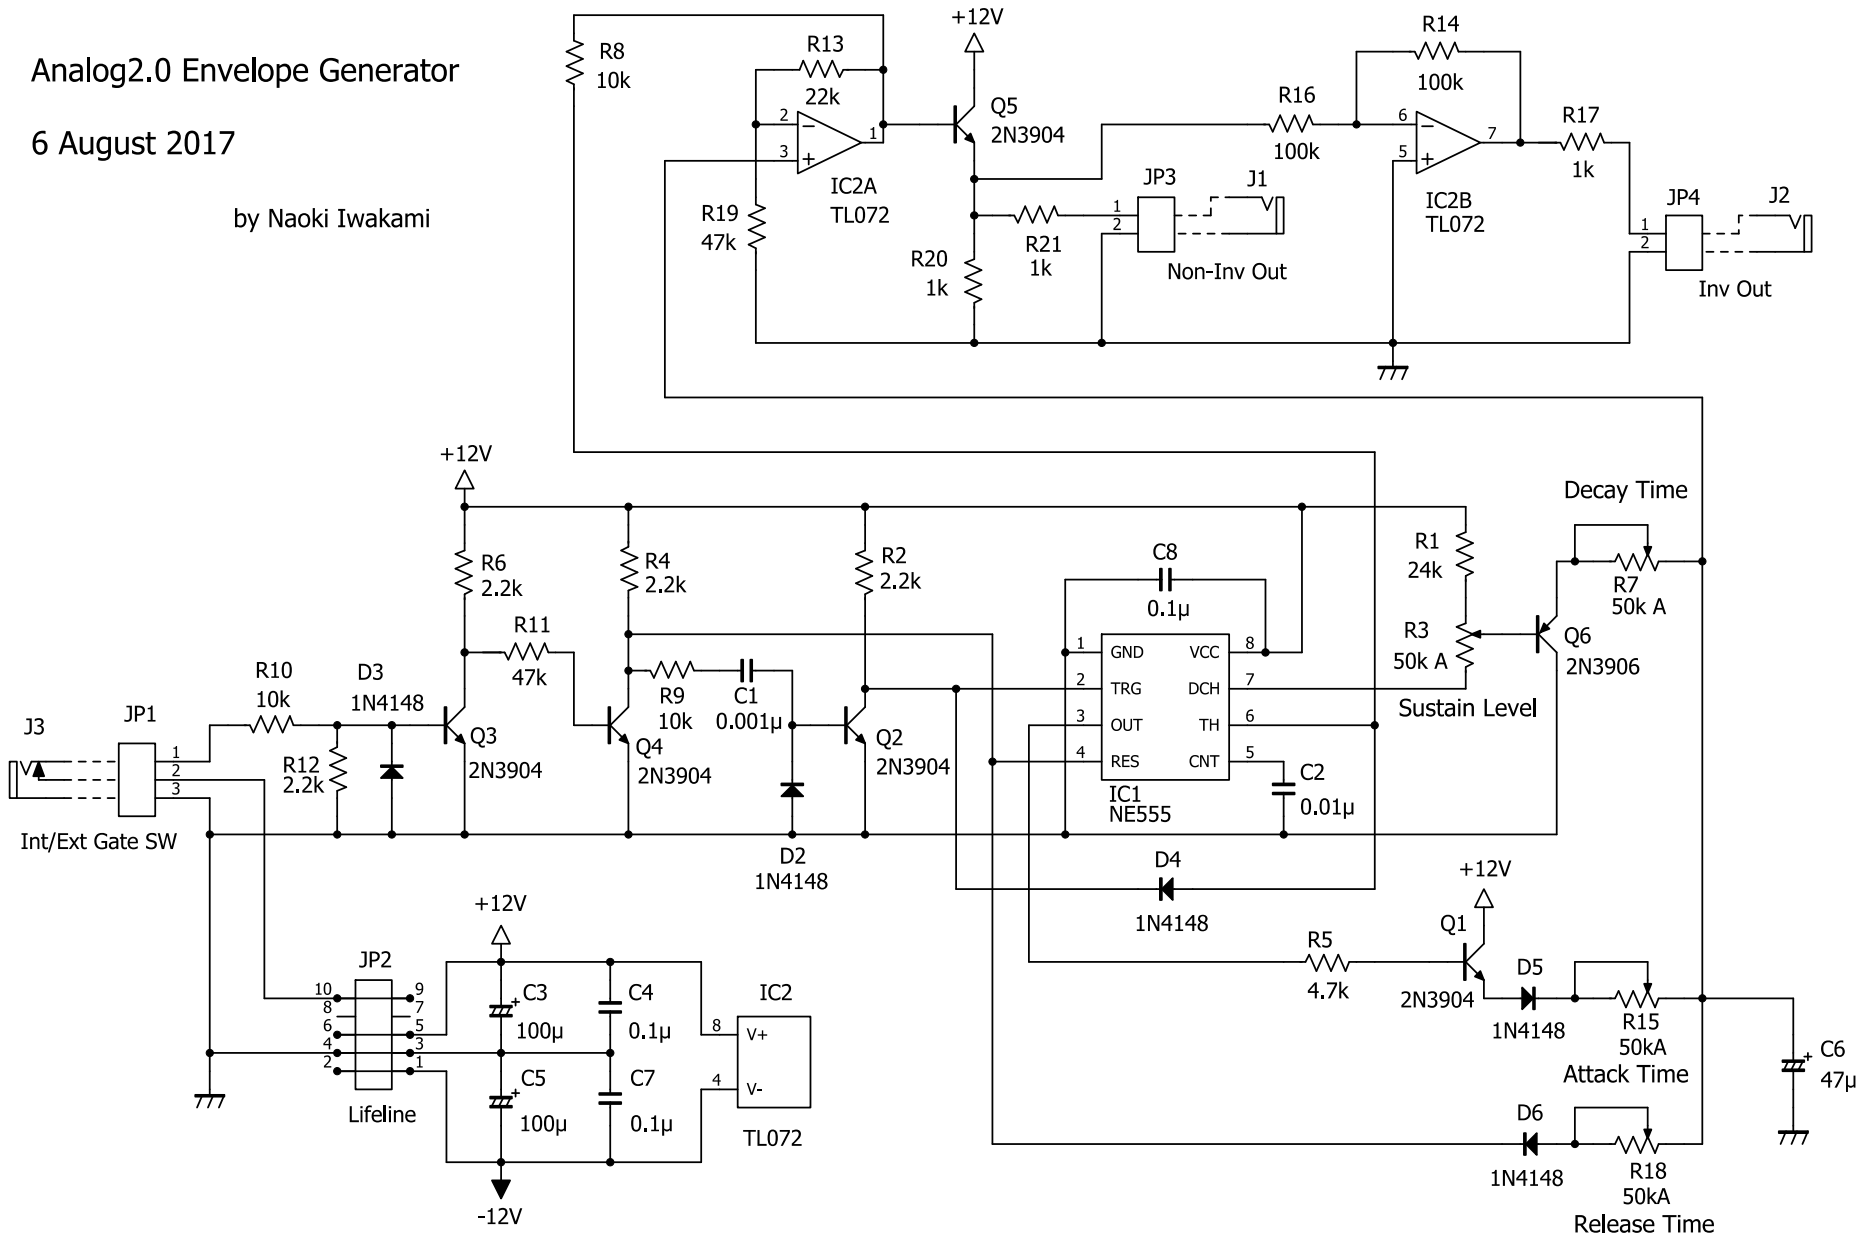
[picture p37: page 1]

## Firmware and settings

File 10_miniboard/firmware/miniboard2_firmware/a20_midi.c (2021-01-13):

/* MInI Board II controller (ATTiny2313) */

#include <avr/io.h>
#include <avr/interrupt.h>

/*---------------------------------------------------------*/
/* Fuse Bytes                                              */
/*---------------------------------------------------------*/
// We change only fuse low byte as follows.
// 1 1 1 0 1 1 1 1
// | | | | | | | +-- CKSEL0 : 1
// | | | | | | +---- CKSEL1 : 1
// | | | | | +------ CKSEL3 : 1
// | | | | +-------- CKSEL4 : 1 -- crystal, 8MHz or above
// | | | +---------- SUT0   : 1
// | | +------------ SUT1   : 1 -- startup: 16K CK, delay: 14CK + 65 ms
// | +-------------- CKOUT  : 1
// +---------------- CKDIV8 : 1
FUSES = {
    .low = 0xff,
    .high = HFUSE_DEFAULT,
    .extended = EFUSE_DEFAULT
};

/*---------------------------------------------------------*/
/* Port Assignment                                         */
/*---------------------------------------------------------*/
#define CV_PITCH   OCR0A
#define CV_BEND    OCR1A

#define GATE1       PORTB1

#define GATE1_ON(x)     (PORTB |= (1 << GATE1))
#define GATE1_OFF(x)    (PORTB &= ~(1 << GATE1))

/*---------------------------------------------------------*/
/* Constants                                               */
/*---------------------------------------------------------*/
#define true  1
#define false 0

#ifndef F_CPU
#define F_CPU    20000000   /*  20MHz clock */
#endif

/*---------------------------------------------------------*/
/* Serial interface for MIDI                               */
/*---------------------------------------------------------*/
#define UART_BAUD_RATE 31250
#define UART_BUF_SIZE    16  // must be power of 2
#define UART_PTR_MASK    (UART_BUF_SIZE - 1)

/* baud register value caluculation */
#define UART_BAUD_SELECT (F_CPU / (UART_BAUD_RATE * 16l) - 1)

/* input data queue and pointers */
volatile uint8_t uart_rx_queue[UART_BUF_SIZE];  // UART read queue. This is a ring queue with size UART_BUF_SIZE.
volatile uint8_t uart_rx_producer_pos;
volatile uint8_t uart_rx_consumer_pos;

/*---------------------------------------------------------*/
/* MIDI decoder                                            */
/*---------------------------------------------------------*/

/* MIDI Channel Voice message */
#define MSG_NOTE_OFF          0x80
#define MSG_NOTE_ON           0x90
#define MSG_POLY_KEY_PRESSURE 0xA0
#define MSG_CONTROL_CHANGE    0xB0
#define MSG_PROGRAM_CHANGE    0xC0
#define MSG_CHANNEL_PRESSURE  0xD0
#define MSG_PITCH_BEND        0xE0

/* MIDI Control Changes */
#define CC_BREATH                0x02
#define CC_EXPRESSION            0x0B
#define CC_DAMPER_PEDAL          0x40

/* MIDI Channel Mode Messages */
#define CC_ALL_SOUND_OFF         0x78
#define CC_RESET_ALL_CONTROLLERS 0x79
#define CC_LOCAL_CONTROL         0x7A
#define CC_ALL_NOTES_OFF         0x7B
#define CC_OMNI_MODE_OFF         0x7C
#define CC_OMNI_MODE_ON          0x7D
#define CC_MONO_MODE_ON          0x7E
#define CC_POLY_MODE_ON          0x7F

/* MIDI System Messages */
#define SYSEX_IN  0xF0
#define SYSEX_OUT 0xF7

/* MIDI System Real-Time Messages */
#define TIMINIG_CLOCK  0xf8  // The lowest number in the real-time messages

#define MAX_DATA 0x7F

/* Notes */
#define C0 0x0B

/* Macros used by MIDI decoder */
#define isSystemExclusive(status)     ((status) == SYSEX_IN)
#define isChannelStatus(status)       ((status) < SYSEX_IN)
#define getMessageFromStatus(status)  ((status) & 0xF0)
#define getChannelFromStatus(status)  ((status) & 0x0F)

volatile uint8_t midi_status;      // MIDI status
volatile uint8_t midi_message;     // MIDI message (= status & 0xF0)
volatile uint8_t midi_channel;     // MIDI channel (= status & 0x0F)

volatile uint8_t target_midi_channel; // The decoder picks up only this channel

volatile uint8_t midi_data[2];     // MIDI data buffer
volatile uint8_t midi_data_ptr;    // MIDI data buffer pointer
volatile uint8_t midi_data_length; // Expected MIDI data length
volatile uint8_t midi_data_ready;  // data ready flag

static void set_cv();
static void pitch_bend(uint8_t lsb, uint8_t msg);

/*---------------------------------------------------------*/
/* Controllers                                             */
/*---------------------------------------------------------*/
#define MAX_NOTE_COUNT 8

// Voice controller
volatile uint8_t  voice_CurrentNote;
volatile uint8_t  voices_NotesCount;
volatile uint8_t  voices_Notes[MAX_NOTE_COUNT];

// other controller values
// Note that these values are not always equivalent to actual
// CV values since we apply anti-click mechanism to the CV values in
// transition to make the pitch change smooth.
volatile uint16_t ctrl_PitchBend;
volatile uint8_t ctrl_PitchBend_updating;


/*---------------------------------------------------------*/
/* Keyboard reader states                                  */
/*---------------------------------------------------------*/
volatile uint8_t key_prev;
volatile uint8_t tone_factor;

////////////////
// Initializers
//

/**
 * Initializes the UART interface
 */
void init_uart(void)
{

    uint16_t baud = UART_BAUD_SELECT;
    UBRRH = (uint8_t)(baud >> 8);
    UBRRL = (uint8_t)baud;
    UCSRB = (1<<RXCIE)|(1<<RXEN);

    uart_rx_producer_pos = 0;
    uart_rx_consumer_pos = 0;
}

/**
 * Initializes timers
 */
void init_timer(void)
{
    /* Timer0 configuration */
    TCCR0A = (1<<COM0A1) /*|(1<<COM0A0)*/|(1<<COM0B1)|(1<<COM0B0)|(1<<WGM01)|(1<<WGM00);
    TCCR0B = (1<<CS00);
    TIMSK = _BV(TOIE0);

    TCCR1A = (1<<COM1A1)|(1<<COM1A0)|(1<<COM1B1)|(1<<COM1B0)| _BV(WGM11) | _BV(WGM10);
    TCCR1B = (1<<WGM12) | _BV(CS10);

    TIMSK |= _BV(TOIE1);

    /*
     * Time1 configuration
     *
     * Waveform generation : Fast PWM, 10bit
     * Clock               : No prescaling
     * OC1A initialization : Reset
     * OC1B initialization : Reset
     */
    TCNT1 = 0x0000;
    /*
      TCCR1A = 0xA3;
      TCCR1B = 0x9;
      ICR1 = 0xFFF;
    */
    CV_PITCH   = 0xFF;  // pitch CV
}

void init_midi_controllers()
{
    // ctrl_PitchBend = 8192 >> 4; // 0x20 0x00
    ctrl_PitchBend_updating = 0;
    pitch_bend(0x00, 0x40);  // set neutral
    
    voices_NotesCount = 0;
    voice_CurrentNote = 68;  // A4
    set_cv();

    // Set target MIDI channel.  If the button is on, we read the channel from the octave switch.
    // Otherwise the channel is 1 (but the internal value is zero based).
    target_midi_channel = (PIND & _BV(PD2)) ? 0 : ((PIND >> 3) ^ 0x0f);

    GATE1_OFF();
}

/**
 * iosetup()
 * Initializes I/O ports.
 */
void iosetup(void)
{
    /* setup output data port */
    DDRB = _BV(PB0) |  // tuning tone
           _BV(PB1) |  // gate out
           _BV(PB2) |  // note CV
           _BV(PB3);   // pitch bend

    PORTB = 0xf0; // key reader

    PORTD = _BV(PD2) | _BV(PD3) | _BV(PD4) | _BV(PD5) | _BV(PD6);
}


/**
 * Initialize MIDI decoder
 */
void init_midi_decoder()
{
    midi_status = 0;
    midi_message = 0;
    midi_channel = 0xFF;
    midi_data_ptr= 0;
    midi_data_length= 1;
    midi_data_ready = 0;
}

////////////////////////////////
// UART data receiver functions

/**
 * Receive Complete Interrupt (RCI) handler
 * This handler fetch a byte from UART receive register UDR and pushes
 * it to the data queue via input pointer uart_rx_push_ptr.
 */
ISR(USART_RX_vect)
{
    uart_rx_queue[uart_rx_producer_pos++] = UDR;
    uart_rx_producer_pos &= UART_PTR_MASK;
}

/**
 * Tries pulling a byte from RX queue.
 * @return Read byte if the data was available, otherwise -1.
 */
int16_t uart_getchar(void)
{
    if (uart_rx_consumer_pos != uart_rx_producer_pos) {
        uint8_t c = uart_rx_queue[uart_rx_consumer_pos++];  // consume a byte from the queue
        uart_rx_consumer_pos &= UART_PTR_MASK;
        return c;
    } else {
        return -1; /* queue is empty */
    }
}

//-----------------------------------------------
// Update PWM ratio for Pitch CV

/**
 * Set CV PWM ratio by current note
 */
void set_cv()
{
    uint8_t pwm_value;
    pwm_value = voice_CurrentNote > C0 ? voice_CurrentNote - C0 : 1;
    CV_PITCH = pwm_value * 2;
}

/**
 * Pitch Bend Channel Message Handler.
 * This function calculates the ctrl_PitchBend value.
 * CV_BEND register follows the value in timer1 interrupt handler.
 */
void pitch_bend(uint8_t lsb, uint8_t msb)
{
    uint16_t temp = 1023 - (lsb / 16 + msb * 8);
    ctrl_PitchBend_updating = 1;
    ctrl_PitchBend = temp * 5 / 32;
    ctrl_PitchBend_updating = 0;
}

/**
 * Note Off Channel Message Handler.
 * The highest note wins when multiple notes are on.
 */
void note_off(uint8_t note_number)
{
    uint8_t i;
    uint8_t flg = false;

    // Find
    for (i = 0; i < voices_NotesCount; i++) {
        if (flg) {
            voices_Notes[i-1] = voices_Notes[i];
        }
        if (voices_Notes[i] == note_number) {
            flg = true;
        }
    }

    if (flg) {
        --voices_NotesCount;
    }
    else {
        // This is not a voice we are tracking
        return;
    }

    // Update states of the instruments
    if (voices_NotesCount == 0) {
        // There are no voices on the table.  It's time to switch the gate off
        GATE1_OFF();
    }
    else {
        // Update the CV to current highest.  Keep the gate on.
        voice_CurrentNote = voices_Notes[0];
        set_cv();
    }
}

void all_notes_off()
{
    // clear voices table and switch the gate off
    voices_NotesCount = 0;
    GATE1_OFF();
}

/**
 * Note On Channel Message Handler.
 * The highest note wins when multiple notes are on.
 */
void note_on(uint8_t note_number, uint8_t velocity)
{
    uint8_t i;

    // note on with velocity zero is equivalent to note off
    if (velocity == 0) {
        note_off(note_number);
        return;
    }

    // Finish the work quickly if the voice table is empty
    if (voices_NotesCount == 0) {
        ++voices_NotesCount;
        voices_Notes[0] = note_number;
        voice_CurrentNote = note_number;
        set_cv();
        GATE1_ON();
    }

    // Update the current voice table.
    uint8_t pos = voices_NotesCount;
    for (i = 0; i < voices_NotesCount; i++) {
        // If we already have the note we do nothing.
        if(voices_Notes[i] == note_number) {
            return;
        }

        // Search for the insertion point
        if (note_number > voices_Notes[i]) {
            pos = i;
            break;
        }
    }

    // Insert the new note
    if (pos < MAX_NOTE_COUNT) {
        if (++voices_NotesCount > MAX_NOTE_COUNT) {
            voices_NotesCount = MAX_NOTE_COUNT;
        }

        for (i = voices_NotesCount; --i > pos; ) {
            voices_Notes[i] = voices_Notes[i-1];
        }
        voices_Notes[pos] = note_number;
    }

    voice_CurrentNote =  voices_Notes[0];

    set_cv();
    GATE1_ON();
}

void control_change(uint8_t control_number, uint8_t value)
{
    switch (control_number) {
    case CC_BREATH:
    case CC_EXPRESSION:
        // set_volume(midi_data[1]);
        break;
    case CC_RESET_ALL_CONTROLLERS:
        init_midi_controllers();
        break;
    case CC_LOCAL_CONTROL:
        // TODO: We should enable/disable on-board keyboard when we get this
        break;
    case CC_ALL_SOUND_OFF:
    case CC_ALL_NOTES_OFF:
        // all_notes_off();
        break;
    }
}

/**
 * Handle MIDI Channel Messages
 */
void handle_midi_channel_message()
{
    // do nothing for channels that are out of scope
    if (midi_channel != target_midi_channel) {
        return;
    }

    switch(midi_message) {
    case MSG_NOTE_OFF:
        note_off(midi_data[0]);
        break;
    case MSG_NOTE_ON:
        note_on(midi_data[0], midi_data[1]);
        break;
    case MSG_CONTROL_CHANGE:
        control_change(midi_data[0], midi_data[1]);
        break;
    case MSG_PITCH_BEND:
        pitch_bend(midi_data[0], midi_data[1]);
        break;
    default:
        // do nothing for unsupported channel messages
        break;
    }
}

void consume_midi_byte(uint16_t rxByte)
{
    if (rxByte >= TIMINIG_CLOCK) {
      // we break here to avoid the system real-time message affects the midi_status.
      return;
    }
  
    if (isSystemExclusive(midi_status)) {
        if (rxByte == SYSEX_OUT) {
            midi_status = SYSEX_OUT;
        }
        return; // ignore any sysex data
    }

    if (rxByte > SYSEX_IN) {
        midi_status = rxByte;
        midi_data_length = 1; // We don't really parse system messages but toss every data
        midi_data_ptr = 0;
        return;
    }

    if (rxByte == SYSEX_IN) {
        midi_status= SYSEX_IN;
        return;
    }

    if (rxByte > MAX_DATA) {
        midi_status = rxByte;
        midi_channel = getChannelFromStatus(midi_status);
        midi_message = getMessageFromStatus(midi_status);

        // check the message and determine the
        switch(midi_message) {
        case MSG_NOTE_OFF:
        case MSG_NOTE_ON:
        case MSG_POLY_KEY_PRESSURE:
        case MSG_CONTROL_CHANGE:
        case MSG_PITCH_BEND:
            midi_data_length = 2;
            break;
        case MSG_PROGRAM_CHANGE:
        case MSG_CHANNEL_PRESSURE:
            midi_data_length = 1;
            break;
        }
        midi_data_ptr = 0;
        return;
    }

    // OK we are reading a data byte
    midi_data[midi_data_ptr++] = rxByte;
    if (midi_data_ptr ==  midi_data_length) {
        midi_data_ptr = 0;

        // We handle the data
        if ( isChannelStatus(midi_status) ) {
            handle_midi_channel_message();
        }
    }
}

#define BUZZ_CYCLE (F_CPU / 0xff / 440 / 2)

ISR(TIMER0_OVF_vect)
{
    static uint8_t buzzcount = 0;

    if (++buzzcount == BUZZ_CYCLE) {
        buzzcount = 0;
        PORTB ^= tone_factor;
    }
}

ISR(TIMER1_OVF_vect)
{
    static uint16_t button_count = 0;
    uint8_t key;
    uint8_t octave;

    if (CV_BEND != ctrl_PitchBend && ! ctrl_PitchBend_updating) {
        if (CV_BEND > ctrl_PitchBend) {
            --CV_BEND;
        }
        else {
            ++CV_BEND;
        }
    }

    // check the keyboard
    //
    octave = ((PIND >> 3) ^ 0x0f) * 12;
    key = ((PINB >> 4) ^ 0x0f);
    if (key) {
        key += octave;
    }
    if (key != key_prev) {
        if (key_prev) {
            note_off(key_prev + C0);
        }
        if (key) {
            note_on(key + C0, 127);
        }
    }
    key_prev = key;

    if (! (PIND & _BV(PD2))) {
        ++button_count;
    }
    else {
        button_count = 0;
    }
    if (button_count >= 19531) {
        tone_factor ^= _BV(PORTB0);
        button_count = 0;
    }
}

int main(void)
{
    iosetup();
    init_uart();
    init_timer();

    init_midi_decoder();
    init_midi_controllers();

    key_prev = 0;
    tone_factor = 0;

    sei();

    while (true) {
        uint16_t rxByte = uart_getchar();
        if (rxByte != -1) {
            consume_midi_byte(rxByte);
        }
    }
}

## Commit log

2017-09-12 miniboard2: renamed a few variables and fixed comments
    [a20_midi.c]
2017-09-12 added a mini board 2 firmware project
2017-09-15 miniboard2 doc: fixed wrong link to schematic
2017-09-15 miniboard2: doc: attached a board image
2017-09-16 miniboard2: readme: try fixing link to schematic
2017-09-16 renamed power PCB component side layout file
2017-09-16 added schematic of lifeline cable
2017-09-16 added wiring photos
2017-09-16 put png version of N&M schematic
2017-09-16 Updated schematics, and PCB files to the latest
2017-09-17 Added resources of additional modules
    [analog_sequencer5.sch, phaser.brd, phaser.sch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]
2017-09-27 Modified MiniBoard 2 firmware fuse low byte
2017-10-01 Added power supply module parts list
2019-09-23 Fixed wrong pin numbers of output buffer in Phase Shifter schematic
2021-01-13 Bug fixes to MIDI/CV converger firmware
    [a20_midi.c]
